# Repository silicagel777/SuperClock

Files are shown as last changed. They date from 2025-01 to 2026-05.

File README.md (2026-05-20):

# LED Matrix Super Clock

A DIY desk clock with retro-style dot matrix display

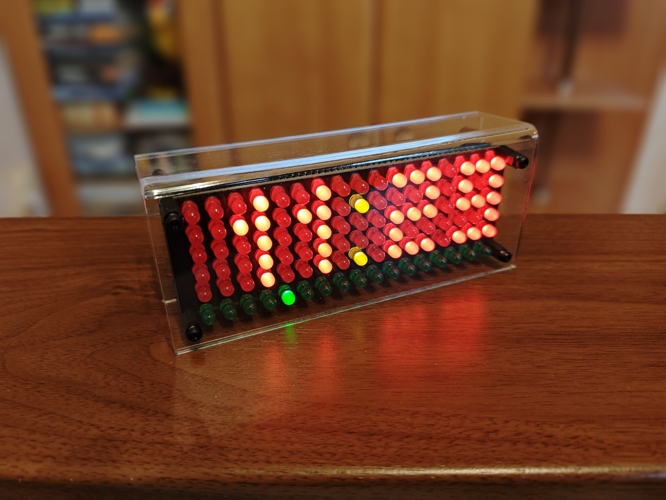
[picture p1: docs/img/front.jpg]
Front photo

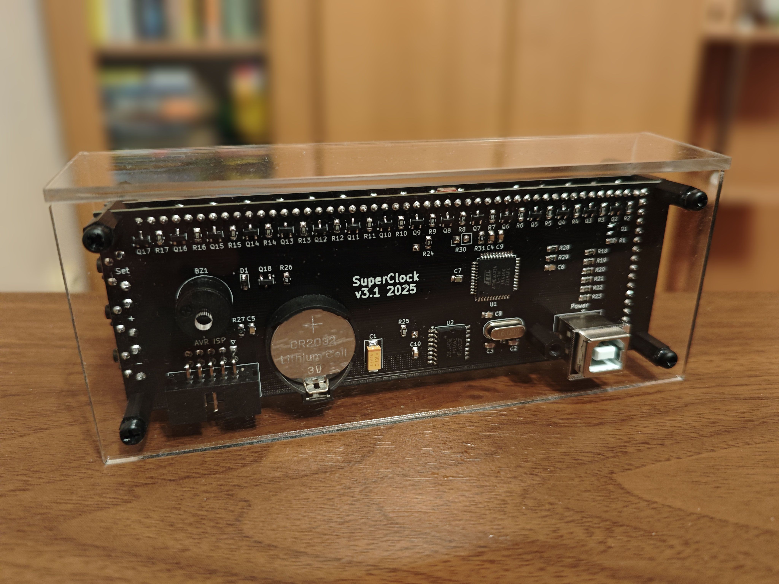
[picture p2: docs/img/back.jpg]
Back photo


## Features

- A retro-style dot matrix display:
    - 17x6 5mm LED matrix
    - Different LED colors for main area, status bar and number separator
    - No flickering, ghosting or uneven brightness
    - High refresh rate of 460Hz
    - 8-bit global brightness and 3-bit per-pixel brightness
    - Global brightness is automatically (and smoothly) adjusted by ambient conditions, just like on your phone!
- Accurate timekeeping:
    - Temperature-compensated crystal clock (DS3231SN chip)
    - Backup power to keep the clock ticking (CR2032 battery)
    - Displays minute, hour, day, weekday, month, year and even ambient temperature
    - Green status bar tracks seconds (incremented every 4s)
    - Five alarms with melody
- Intuitive (kinda) user interface with three buttons
- Cool acrylic glass frame
- Powered by any USB brick through a Type-B cable
    - Finally, a reason to pick up that old printer cable from your drawer!
- Built around ATmega32 microcontroller, with firmware written in C++
    - Uses **every** I/O pin on ATmega32, no wasted potential!
- No AI and no internet connection! (yup, that's a feature nowadays...)
- Totally open-source!

## Documentation

- [Hardware docs](docs/hardware.md)
    - Includes schematics, design files, parts list and even assembly tips
- [Frame docs](docs/frame.md)
    - Describes the acrylic glass frame
- [Software docs](docs/firmware.md)
    - How to flash firmware or set up development tools if you want to modify it
- [LED matrix notes](docs/matrix.md)
    - Notes on how the LED matrix works
- [User manual](docs/manual.md)
    - What do these buttons do?!

## TODO list

- [x] Write this readme
- [x] Make first public release
- [ ] Animated minute/hour transitions
- [ ] Reorganize font system
- [ ] More levels for highest and lowest brightness?
- [ ] Use C++ namespaces?
- [ ] Abstractions for pins and timers?
- [ ] Snake mode? :D

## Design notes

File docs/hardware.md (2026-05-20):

# Hardware notes

## PCBs

<a href="img/pcbs_outside.jpg">Photo of PCBs (outside)</a>
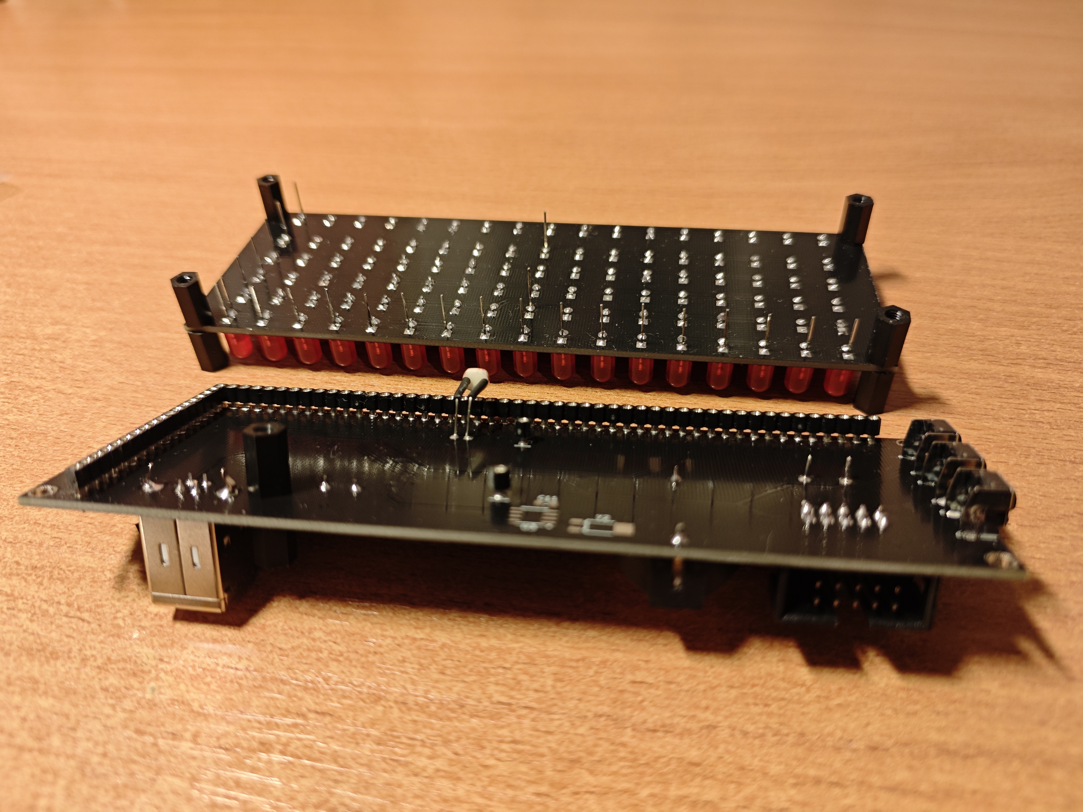
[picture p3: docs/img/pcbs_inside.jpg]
Photo of PCBs (inside)


The clock is built with two PCBs: the front one that houses LEDs (matrix) and the back one that contains everything else (controller). You can find schematic PDFs, KiCAD design files and Gerber archives here:

- [Matrix board files](../hw/matrix/)
    - [PDF schematic](../hw/matrix/SuperClockMatrix.pdf)
    - [Gerber archive](../hw/matrix/gerber/superclockmatrix.zip)
- [Controller board files](../hw/controller/)
    - [PDF schematic](../hw/controller/SuperClockController.pdf)
    - [Gerber archive](../hw/controller/gerber/superclockcontroller.zip)

The provided Gerber files can be used to order the boards from a multitude of Chinese PCB prototyping factories. I've ordered mine from [Elecrow](https://www.elecrow.com/), but you can also try [JLCPCB](https://jlcpcb.com/) or anything else. Note that these PCBs are wider than the typical 100mm limit, so you are going to pay a little bit more than usual. But it's worth it, I promise!

I recommend ordering the boards with black soldermask and no manufacturer marks (so that the factory won't write anything on the front area). Elecrow makes boards with no markings by default, while JLCPCB offers "Remove Mark" as an option.

## Parts list

### LED matrix

You are going to need a lot of LEDs, so I recommend making a bulk order instead of buying them locally one-by-one. I've bought all the LEDs in 100pcs bags from "[Chanzon Store](https://aliexpress.com/item/32283531722.html)" on AliExpress.

Reference | Quantity | Part name | Notes
--- | --- | --- | ---
\- | 83 | 5mm diffused red LED | You can pick these LEDs anywhere, although I've noticed that no-name red LEDs can be a tad dimmer than the branded ones.
\- | 17 | 5mm diffused green LED | Green LEDs exist in two variants: "green" (515-520nm) and "yellow-green" (570-575nm). You need to get the former ones, as they are **much** brighter. And, of course, if the seller doesn't describe the LED variant, you are going to receive the worst one! But don't worry if you happen to get dim LEDs, all you need is to replace a single resistor.
\- | 2 | 5mm diffused yellow LED | The only LEDs worth buying in retail, as you only need two of them! You can also try the orange ones here.

### Controller board

Reference | Quantity | Part name | Notes
--- | --- | --- | ---
BT1 | 1 | CR2032 generic holder | I don't know the correct part number for this one, but it's widely available on AliExpress, just search for "CR2032 battery holder"
BZ1 | 1 | Generic passive buzzer: 12mm x 8.5mm, 42R (5V) | I don't know the correct part number for this one either, but it's widely available on AliExpress, just search for "passive buzzer 42R"
C1 | 1 | SMD-C 100uF tantalum capacitor | I've used TAJC107K016RNJ, but this can be any matching capacitor
C2-C3 | 2 | SMD 0805 12pF ceramic capacitor | -
C4-C10 | 7 | SMD 0805 0.1uF ceramic capacitor | -
D1 | 1 | 1N5819WS | This diode is used for voltage spike protection in buzzer driving circuit
J1-J4 | 4 | Round-pin single-row machined headers | The controller board requires 1x49, 1x17, 1x1 and 1x1 round-pin machined connectors. Sadly, the first size does not exist in the wild, but you can buy a bunch of 1x40 ones and cut/combine them with ease. You can find the connectors on AliExpress, just search for "round pin female header".
J5 | 1 | USB Type-B 180-degree socket | This is the biggest USB socket, the same kind as in printers or Arduino UNO. The socket must be a vertical one, with pins on the opposite side of the socket. I don't know the correct part number for this, but you can find them on AliExpress, just search for "usb type-b socket 180"
J6 | 1 | 2x5 90-degree IDC socket | The socket for USBasp programmer, used to flash ATmega32. Part numbers vary: it can be IDC-10MR, BH-10R, DS1013-10R or something completely else. You can find them on AliExpress by searching "idc connector"
Q1-Q18 | 18 | 2N7002K | A SOT-23 N-channel MOSFET. I recommend using 2N7002K here: these come with built-in ESD protection diodes. But you can also use the more popular ones instead: 2N7002, BSS138. Just be morally prepared to replace a few busted ones, as they can be killed by ESD discharge while soldering. I don't recommend using higher-power MOSFETs like AO3400, AO3416, IRLML2502, etc, as their higher input capacitance causes slight [display ghosting](matrix.md#led-ghosting) on lowest brightness.
R18-R22, R24-R25 | 7 | SMD 0805 220R resistor | -
R23 | 1 | SMD 0805 3.3K resistor | -
R26, R31 | 2 | SMD 0805 10K resistor | -
R27-R29 | 3 | SMD 0805 4.7K resistor | -
R30 | 1 | GL5516 photo-resistor | -
SW1-SW3 | 3 | 90-degree tactile switch | I don't know the correct part number for this one, but it's widely available on AliExpress, just search for "angle tactile switch"
U1 | 1 | ATmega32A-AU | Should work with any ATmega32 in TQFP-44 package
U2 | 1 | DS3231SN | There also exists a less-accurate part called DS3231M. Both of them work, but you want to get the best one!
Y1 | 1 | HC49S 16MHz Crystal | External crystal for ATmega32
~~R1-R17~~ | ~~17~~ (do not place) | ~~SMD 0805 resistor~~ | These were used in an earlier attempt to counteract [display ghosting](matrix.md#led-ghosting), but turned out to cause more harm than good: green LEDs did not like the reverse voltage at all, and started failing in a few months! The ghosting issues were eventually resolved by other means, so don't solder these resistors at all.
~~U3~~ | ~~1~~ (do not place) | ~~DS1307ZN~~ | I've added this one just in case DS3231 chips become unavailable, but luckily that didn't happen! Don't solder DS3231 and DS1307 together, as they use the same I2C address.
~~Y2~~ | ~~1~~ (do not place) | ~~32.768kHz clock crystal~~ | External crystal for DS1307
~~C11~~ | ~~1~~ (do not place) | ~~SMD 0805 0.1uF ceramic capacitor~~ | Bypass capacitor for DS1307

### Miscellaneous

Reference | Quantity | Part name | Notes
--- | --- | --- | ---
\- | 9 | M3 10mm male-female nylon standoffs | Used to connect the boards together. You can buy a whole kit of standoffs on AliExpress: search for "m3 nylon standoff kit", they come in nice 10-cell boxes.
\- | 5 | M3 10mm female-female nylon standoffs | Used to connect the boards together.
\- | 8 | M3 nylon screws | Used to attach the acrylic frame

## Assembly notes

Assembling the boards should be fairly straightforward, but here are a few hints:

- Square pads on matrix board are LED cathodes, and round pads are LED anodes. All the LEDs are soldered in the same direction.
- LED legs from the matrix board act as connector pins for the controller board. This means that, looking at matrix board from behind, you **must not** cut the LED cathode pins on the top, LED anode pins on the right, and number separator LED anode pins at the center. Instead, carefully trim them to something around 9mm (that's for 10mm standoffs, adjust accordingly if your PCB spacers are different length).
- Mating the boards for the first time might be tricky: the round-pin machined connectors don't like misaligned stuff. To resolve this, carefully align LED legs with tweezers until they all go into the corresponding holes. Once the pins are properly aligned, further board separation/mating cycles should be much easier.
- The hole near USB socket is to provide some additional strength when the cable is inserted: you can put standoffs here to protect the controller PCB and acrylic frame from being bent too much. But don't worry if you don't have spare standoffs anymore: it seems that there is enough rigidity anyway.
- If you've never soldered SMD parts before: don't be intimidated by them! Working with SMDs is actually way easier than with through-hole ones. All the parts used here are big enough to not be annoying, and the probability of solder bridges becomes very low with a good flux. I recommend buying a hot-air soldering gun if you don't have it already, but you can assemble the controller board easily with soldering iron alone. Remember to solder the SMD parts first, then go for the through-holes.
- Be careful with DS3231SN chip: heating it too much might affect clock accuracy. I recommend soldering it with a temperature-controlled soldering iron instead of hot air gun or reflow oven.

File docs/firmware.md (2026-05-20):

# Software notes

The firmware is written in C++. It can be compiled by [avr-gcc](https://www.nongnu.org/avr-libc/user-manual/overview.html) and flashed by [avrdude](https://github.com/avrdudes/avrdude) through [USBasp](https://www.fischl.de/usbasp/). You can find the latest firmware builds in "Releases" section.

## Flashing firmware

ATmega32 doesn't come with a USB bootloader (and there are no free I/O pins for USB connection anyway), so you are going to need an external programmer tool.

There are lots of ATmega programmers around, and if you are into DIY electronics, chances are high that you already have one! I've used the [USBasp](https://www.fischl.de/usbasp/) programmer from AliExpress. If you have an Arduino board, you can try [Arduino ISP](https://docs.arduino.cc/built-in-examples/arduino-isp/ArduinoISP/) sketch
instead.

To flash firmware, do the following:

- Connect your programmer to your PC and your clock. Most USBasp clones come with a 2x5 ribbon of standard [AVR ISP pinout](https://en.m.wikipedia.org/wiki/File:Isp_headers.svg): if that's the case, just plug the cable into the IDC socket. USB power is not required, as the clock will receive power from the programmer.
- Install drivers for your programmer. For USBasp, you can consult [the official page](https://www.fischl.de/usbasp/).
- Download the programming software. My favorite is [SinaProg](https://cxem.net/software/download/SinaProg2.1.1.rar), but sadly it's very dated, and the official website is long gone. Another good (and maintained) option is [AVRDUDESS](https://github.com/ZakKemble/AVRDUDESS). Both tools are Windows-only and are GUI wrappers for the [avrdude](https://github.com/avrdudes/avrdude) tool. If you run Linux, you can use avrdude directly instead and flash firmware by running a Makefile (see below).
- A factory-fresh ATmega32 is configured to run at 1MHz. Before flashing the firmware, we need to tell it to run from the external crystal at 16MHz and configure a few other settings. This is done by setting fuse bits. You need to set **low byte** to `0xBF` and **high byte** to `0xD1`. Be careful, setting wrong fuse values can brick your chip!
    - For fuses, you need to set a low programming speed in your software, as the default 1MHz clock is not enough for ATmega32 to respond at the fastest speeds.
    - Some USBasp clones from AliExpress run a very old firmware version that doesn't allow configuring programming speed in software: they always use the fastest one instead (1.5MHz). If this happens to you, short the "JP3" jumper on the programmer, it will reduce programming speed.
    - Once the fuses are flashed, you can return to full programming speed.
    - If the chip fails to detect after fuses are flashed, carefully check the soldering around crystal: ATmega32 won't run if it can't make it oscillate.
- Download the latest `*.hex` files from the "Releases" section and load it into the programming software. Flash it, and you should see your clock come alive!

Here is a picture with AVRDUDESS buttons highlighted:

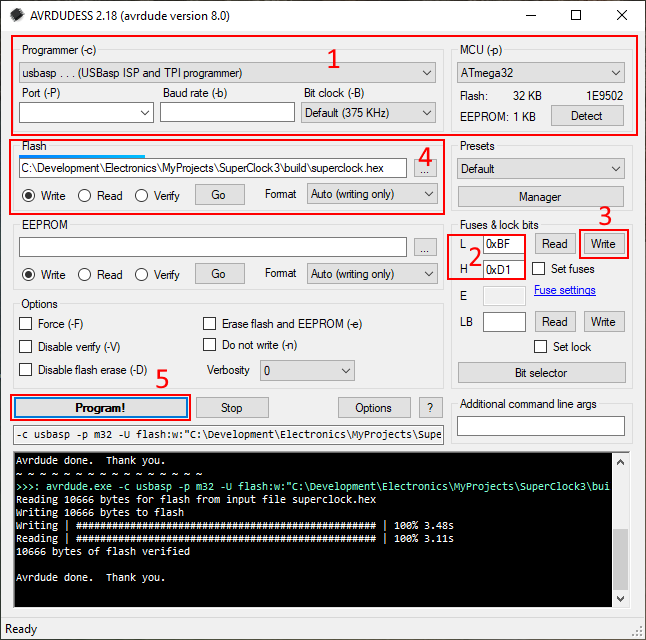
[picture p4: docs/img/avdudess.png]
AVRDUDESS UI


## Developing firmware

### Installing development tools on Windows

- Grab an `avr-gcc` build from [WinAVR](https://winavr.sourceforge.net/)
- Download `make` from [xPack](https://github.com/xpack-dev-tools/windows-build-tools-xpack)
- Download `avrdude` [binary](https://github.com/avrdudes/avrdude)
- Add all the tools to your PATH environment variable (Control Panel -> System -> Advanced System Settings -> Environment Variables). For `avr-gcc` and `make` add `bin` directories, and for `avrdude` add the directory with `avrdude.exe`.

### Installing development tools on Ubuntu or Debian

Run as root: `apt update && apt install gcc-avr binutils-avr avr-libc make avrdude`

### Using `make`

The project comes with a `Makefile` that defines a few commands. Switch to project directory and try the following:

- `make` to build a hex file (you can append `-j<NUMBER>` for parallel builds, for example `make -j16` for an 8-core 16-thread CPU)
- `make font` to update font file
- `make fuse` to write fuse bits through USBasp (do it once before flashing)
- `make flash` to flash firmware through USBasp
- `make clean` to remove build files

### Using Visual Studio Code to develop

With all the build tools in place, setting up the [code editor](https://code.visualstudio.com/) is fairly straightforward!

Firstly, install the [C/C++ plugin](https://code.visualstudio.com/docs/languages/cpp). You'll probably see an annoying pop-up once you open a `*.cpp` file, so this requirement is hard to miss anyway.

Once you are done, create `.vscode/c_cpp_properties.json` in project root to configure the C/C++ plugin. Here is mine:

```js
{
    "configurations": [
        {
            "name": "AVR",
            "includePath": [
                "${workspaceFolder}/src/"
            ],
            "windowsSdkVersion": "10.0.19041.0",
            // adjust your compiler path accordingly
            "compilerPath": "C:/MCU/gcc-avr/bin/avr-g++",
            "compilerArgs": [
                "-std=c++17",
                "-O2",
                "-DF_CPU=16000000UL",
                "-mmcu=atmega32"
            ],
            "cStandard": "c11",
            "cppStandard": "c++17",
            "intelliSenseMode": "gcc-arm"
        }
    ],
    "version": 4
}
```

Create `.vscode/tasks.json` in project root to set up build tasks. You can also install the [quick-run-panel](https://marketplace.visualstudio.com/items/?itemName=davehart.quick-run-panel) plugin to have all the build tasks in your arm's reach. This is optional, as you can just run `make` commands from your command line. Here is mine:

```js
{
    "version": "2.0.0",
    "tasks": [
        {
            "label": "build",
            "type": "shell",
            // change the following to "make -j $(getconf _NPROCESSORS_ONLN)" on Linux
            "command": "make -j $ENV:NUMBER_OF_PROCESSORS",
            "group": "build",
            "problemMatcher": [],
            "presentation": {
                "focus": true
            }
        },
        {
            "label": "run",
            "type": "shell",
            "command": "make flash",
            "problemMatcher": [],
            "group": {
                "kind": "build",
                "isDefault": true
            },
            "presentation": {
                "focus": true
            }
        },
        {
            "label": "clean",
            "type": "shell",
            "command": "make clean",
            "group": "build",
            "problemMatcher": [],
            "presentation": {
                "focus": true
            }
        },
        {
            "label": "font",
            "type": "shell",
            "command": "make font",
            "group": "build",
            "problemMatcher": [],
            "presentation": {
                "focus": true
            }
        }
    ]
}
```

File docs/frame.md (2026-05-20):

# Acrylic frame notes

<a href="img/frame.jpg">Frame photo</a>

You can further enhance the looks of your clock by laser-cutting an acrylic housing. You can find the DWG, DXF and PDF files here:

- [Acrylic frame files](../hw/frame/)

The front panel comes in two flavors: short and long. The short one only covers the front, while the long one is designed with an upper fin that can be bent to cover the top. Most shops charge a premium for acrylic bending, so I recommend ordering the usual laser cutting and then bending it yourself. Here are some tips:

- Place the acrylic on a metal surface with a 90-degree edge (some big metal box) and fix it in place with something heavy. The part you want to bend should be protruding on the side.
- Carefully heat the bend line with sweeping motions of a hot-air gun. I've set mine to 300°C
- Once the bend line softens, carefully bend the sheet

If you are ordering PCBs from [Elecrow](https://www.elecrow.com/), you can also use their acrylic cutting service and have everything in one order. I've used the 3mm transparent (000) acrylic.

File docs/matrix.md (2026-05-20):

# Notes on the LED matrix

Driving a bunch of LEDs... What could have been easier? Well, turns out the reality is hard!

## Introduction

LED matrix driving relies on a phenomenon called "[persistence of vision](https://en.wikipedia.org/wiki/Persistence_of_vision)". There is a really nice [animation](https://en.wikipedia.org/wiki/Dot_matrix#LED_matrix) on Wikipedia that I feel obliged to attach:

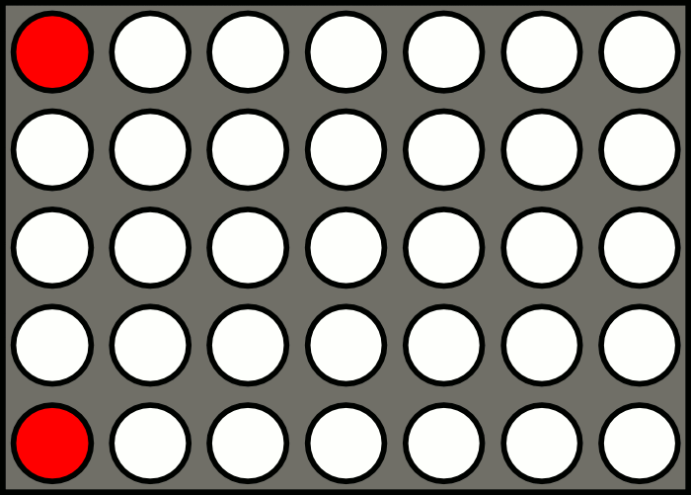
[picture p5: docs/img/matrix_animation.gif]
An animated picture of LED matrix


The LED matrix in this project is driven left to right, just like in the picture! The algorithm is simple: enable rows (LED anodes) and then enable one column (LED cathodes). Once the time comes for another column, switch the old column off, update rows and enable the new column. If you do it fast enough, you'll get an illusion of all columns working simultaneously. But the devil is, of course, in the details!

## Global brightness

Modern LEDs are bright! Good for sunny days, but not-so-good for everything else. The last thing you want is to get blinded by a clock while sneaking to your fridge at night! So, adjustable brightness is essential.

The solution sounds simple: just slap some [pulse-width modulation](https://en.wikipedia.org/wiki/Pulse-width_modulation) (PWM) on! The ATmega32 already comes with several hardware PWM channels. Unfortunately, there are caveats:

- ATmega32 has only four PWM channels, and one is already used to drive the buzzer. Not enough for every row!
- Even if there were enough channels (or we applied PWM to LED power supply), combining them with matrix-driving is tricky: the PWM and column switch frequencies might alias in a bad way, producing nasty flickering. I've learned that the hard way!

Another option is to combine matrix driving and brightness control in a single algorithm. Use one timer interrupt to enable next column, and another to shut it down. You can use the overflow interrupt for the former and compare interrupt for the latter (or vice versa, it doesn't really matter). Timer compare value can be adjusted, so we can get our adjustable brightness!

```
switch to new column here (overflow interrupt)
|
|      disable the column here (compare interrupt)
|      |
v      v
+------+--------------------------+
0      X <-- configurable        255
\_____/\__________________________/
   |                  |
 LEDs on          LEDs off
```

This idea is much better, but has a few caveats as well. Fortunately, they are manageable:

- You need to run your timer very fast to avoid flickering, and the MCU needs to have enough speed to process both interrupts. This is, essentially, PWM implemented in software. Fortunately, ATmega32 is fast enough to run an 8-bit timer at `F_CPU/8` and handle both interrupts. With `F_CPU` set to 16 MHz the speed is enough to have no perceivable flicker.
- If the timer compare value becomes too close to overflow value, interrupt calls will start overlapping, and you won't see any change in brightness. So, you lose some of the lowest and the highest brightness levels. Fortunately, there is a workaround: combine "LEDs on" and "LEDs off" phases in a single interrupt with a software delay (or without delay at all). This workaround must be enabled only when the delay value is low enough, otherwise you'll waste a lot of CPU time waiting.

## Per-pixel brightness

Per-pixel brightness is useful for smooth animation, but not as important as global brightness. I've implemented it on level above matrix driving and global brightness: 

- Each full display refresh (that's when every column gets scanned and we return to the first one) is assigned an incrementing number with an overflow value.
- If pixel brightness value is higher than this number, the pixel is lit, otherwise it's dark.
- You can only have a few brightness levels before egregious flickering becomes apparent: that's because refresh cycle frequency gets reduced for dimmed pixels. I've settled on 8 levels (3-bit): that's enough for simple effects.

## Gamma correction

If you ever tried to regulate LED brightness, you've probably seen this phenomenon: for the first few levels brightness change is very fast, but for the last few levels, brightness change is very slow and barely noticeable.

This happens because our eyes do not perceive brightness linearly, but rather do it logarithmically. So, to provide evenly spaced brightness levels, you need to apply the procedure of [gamma correction](https://en.wikipedia.org/wiki/Gamma_correction). For LEDs this usually involves something like fitting your original brightness to `[0.0, 1.0]` range, raising it to a power of three (`gamma=3.0`), and then resizing it back to match your PWM peripheral scale.

The biggest annoyance here is that a lot of PWM levels are going to be unused, so with 8-bit PWM you'll have way less than 255 distinguishable brightness levels. And for 3-bit PWM there is simply not enough resolution for any meaningful gamma correction.

Fortunately, this LED display adjusts global brightness from ambient conditions! Gamma-correction is not needed here, as we aren't accepting user input: we simply match an existing real-world brightness reading that came from a photo-resistor.

As for the per-pixel brightness: it's not very important, and animation frames can be adjusted to account for uneven brightness levels.

## Automatic brightness flicker

Automatic brightness can be very janky. You've probably seen this on older smartphones: for some ambient brightness conditions, display brightness will annoyingly toggle back and forth between two levels.

There are a few solutions to this:

- Implement something close to a [Schmitt trigger](https://en.wikipedia.org/wiki/Schmitt_trigger) in software. This is especially useful when there are few brightness levels that are spaced far apart.
- Apply some filtering to your sensor data to avoid janky readings.

This LED matrix currently employs the second trick: all photo-resistor readings are passed through a first-order IIR filter. This is the digital equivalent of an [RC circuit](https://en.wikipedia.org/wiki/RC_circuit), and is also known as [exponential smoothing](https://en.wikipedia.org/wiki/Exponential_smoothing). Seems good enough!

## Uneven column brightness

If column brightness depends on the amount of lit pixels in it, then your column drivers are not powerful enough. This is very common for displays that use MCU or 74HC595 pins to drive LEDs. The ATmega32 I/Os are only rated up to 40mA, and 74HC595 outputs are only rated up to 35mA. But a single 5mm LED can be safely driven up to 20mA (or more in short bursts): there is just not enough power to drive a bunch of them!

The solution is to use high-current driver ICs, or add transistor switches. This display uses the latter: all the columns are driven through MOSFETs, so column brightness is always consistent.

## LED ghosting

A very common issue for DIY LED matrix displays is ghosting. The most common cause is software defects: it can happen when LED rows are reconfigured without disabling the column first. If the display is scanned left-to-right, you'll see ghosts to the **left side** of lit pixels.

But there can also be another cause for ghosting: **parasitic capacitance**. Turns out, that LEDs are also capacitors and can store a tiny charge. On fast refresh speeds and small brightness levels this can result in ghosting as well! If display is scanned left-to-right, you'll see a ghosting trail to the **right side** of lit pixels.

The second issue is way nastier, since it can't be fully defeated in software. It can be somewhat reduced by several workarounds, though:

- If no rows in current column are lit, do not enable this column at all!
- If some rows in current column are lit, keep them enabled even when the column is already disabled. Reconfigure them only right before you are ready to enable the next column.

The definitive fix is, however, the hardware one:

- Use a push-pull driver for LED anodes (or add some pull-down resistors), this will help discharge the capacitance in LEDs.
- Use MOSFETs with low parasitic capacitance for LED cathodes (or use BJTs instead), so you won't have extra capacitance on the low side.
    - You might also be tempted to use push-pull drivers (or pull-up resistors) for cathodes as well, but I don't recommend this: some LED types don't like the reverse voltage at all! My green LEDs began failing in a few months after trying that: they slowly started conducting in reverse, and the whole display went wrong.

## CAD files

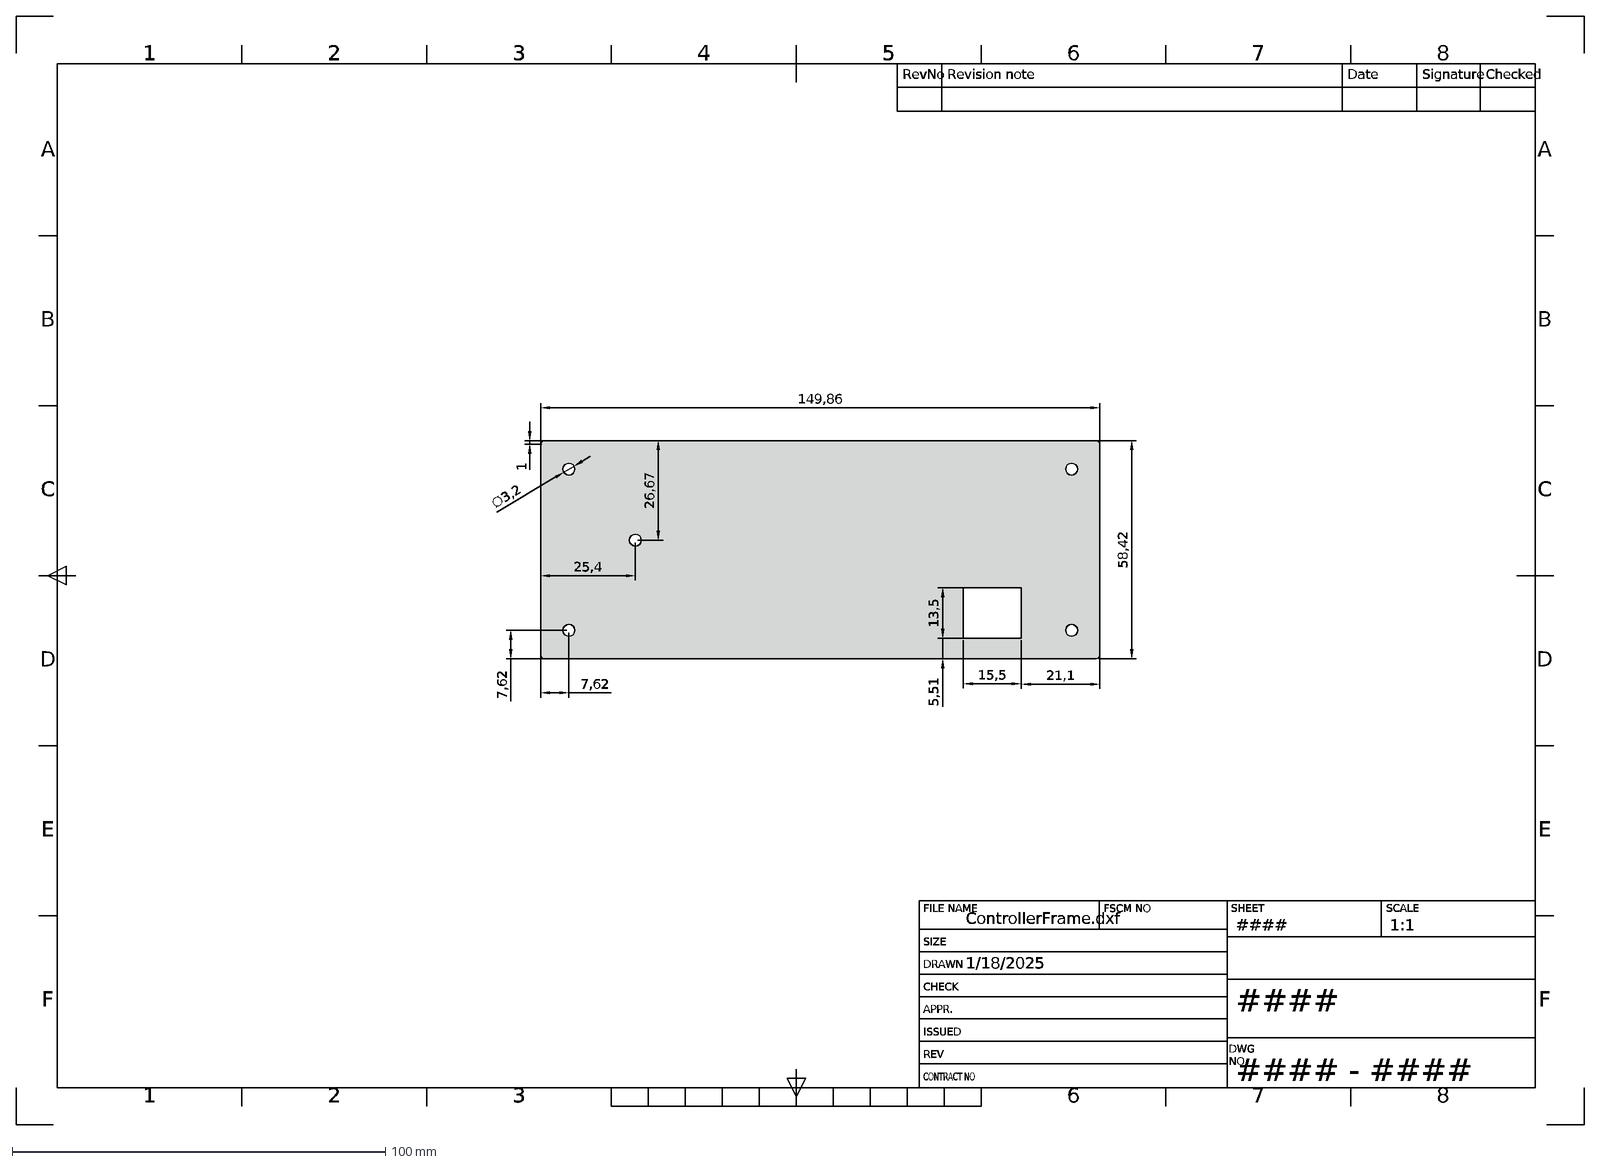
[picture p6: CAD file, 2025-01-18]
hw/frame/ControllerFrame.dxf
####
#### - ####
1:1
ControllerFrame.dxf
1/18/2025
F
1
E
D
3
2
C
B
A
4
7
6
8
5
RevNo
Revision note
Date
Signature
Checked
FSCM NO
SIZE
REV
CONTRACT NO
APPR.
ISSUED
CHECK
DRAWN
FILE NAME
SCALE
SHEET
DWG NO
7,62
149,86
58,42
∅3,2
15,5
13,5
21,1
5,51
25,4
26,67

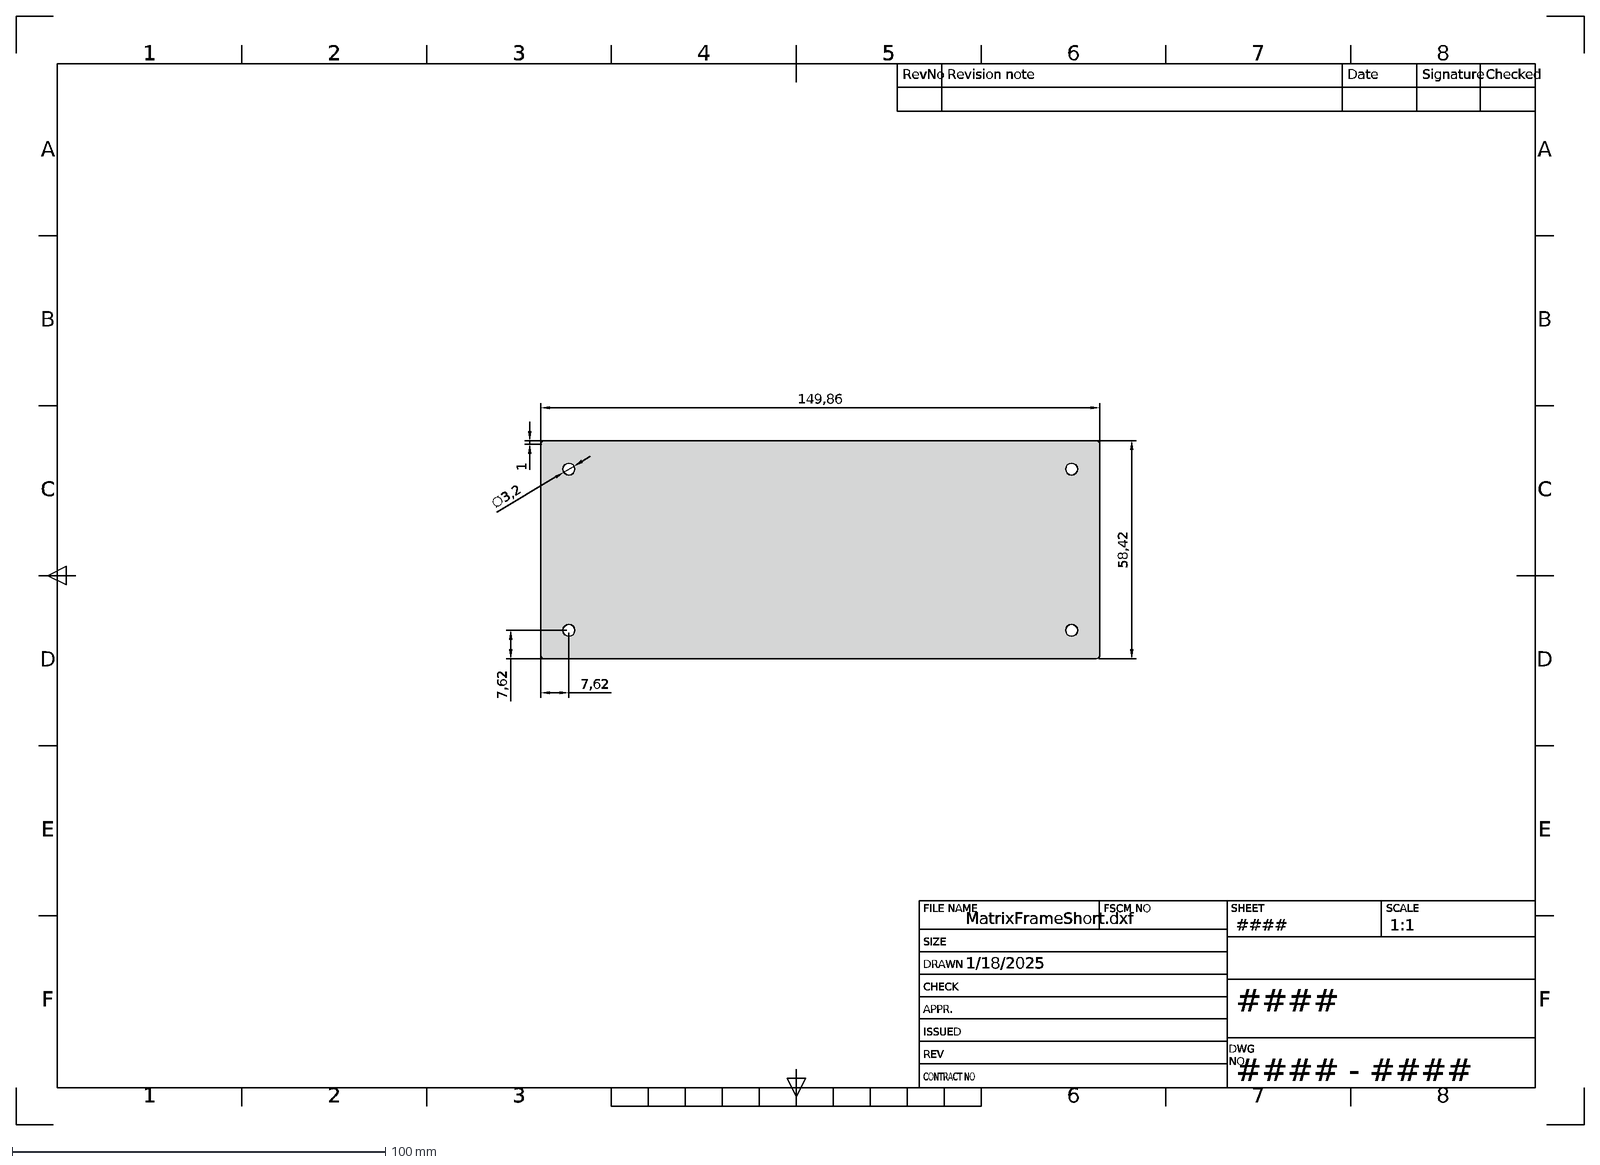
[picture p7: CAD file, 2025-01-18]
hw/frame/MatrixFrameShort.dxf
####
#### - ####
1:1
MatrixFrameShort.dxf
1/18/2025
F
1
E
D
3
2
C
B
A
4
7
6
8
5
RevNo
Revision note
Date
Signature
Checked
FSCM NO
SIZE
REV
CONTRACT NO
APPR.
ISSUED
CHECK
DRAWN
FILE NAME
SCALE
SHEET
DWG NO
7,62
149,86
58,42
∅3,2

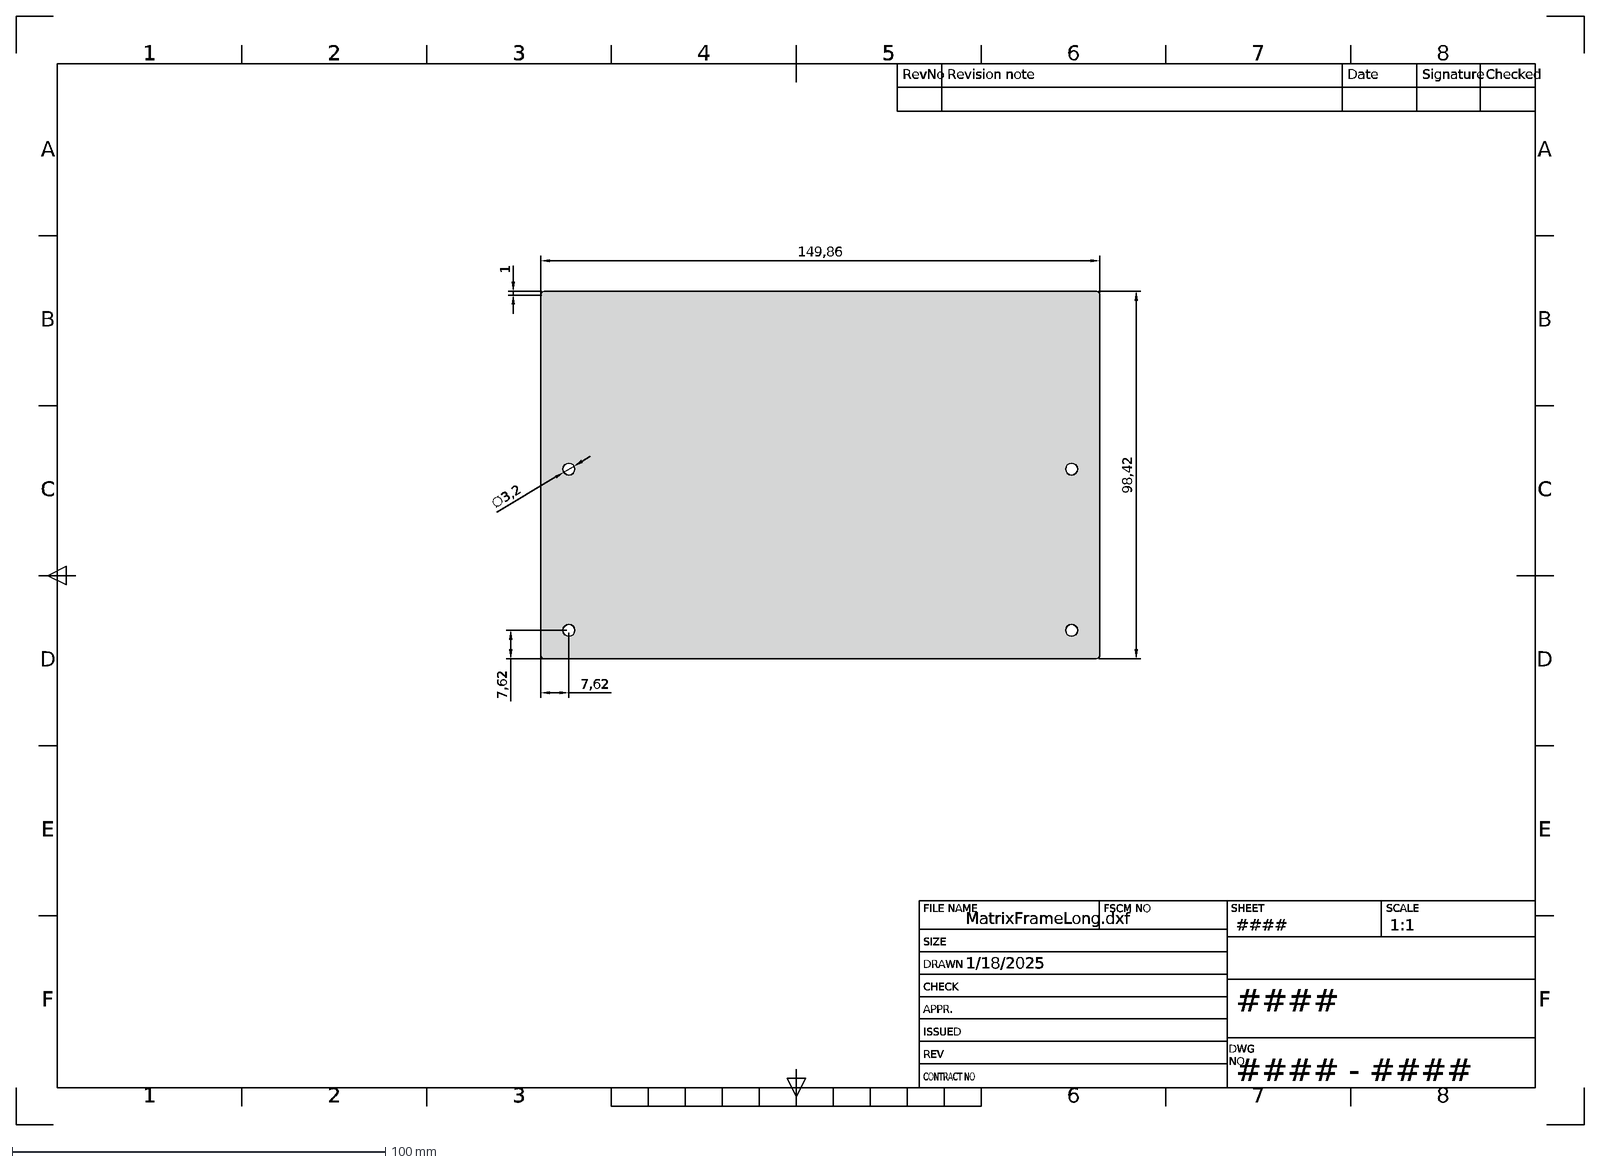
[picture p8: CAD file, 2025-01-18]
hw/frame/MatrixFrameLong.dxf
####
#### - ####
1:1
MatrixFrameLong.dxf
1/18/2025
F
1
E
D
3
2
C
B
A
4
7
6
8
5
RevNo
Revision note
Date
Signature
Checked
FSCM NO
SIZE
REV
CONTRACT NO
APPR.
ISSUED
CHECK
DRAWN
FILE NAME
SCALE
SHEET
DWG NO
7,62
∅3,2
149,86
98,42

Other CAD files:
hw/frame/ControllerFrame.dwg
hw/frame/MatrixFrameLong.dwg
hw/frame/MatrixFrameShort.dwg

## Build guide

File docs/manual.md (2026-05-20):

# User manual

## User interface

The clock comes with three buttons: `MODE`, `PLUS` and `MINUS`. Press `MODE` button to toggle between main modes. Hold `MODE` button to enter setup modes. `PLUS` and `MINUS` actions are relative to current mode.

Here is a mode list with corresponding button actions:

- Main modes:
    - "Clock mode":
        - `MODE` (press): go to "alarm mode"
        - `MODE` (hold): go to "clock setup mode"
        - `PLUS` (press): show date for a few seconds
        - `PLUS` (hold): show year for a few seconds
        - `MINUS` (press): show weekday for a few seconds
        - `MINUS` (hold): show ambient temperature for a few seconds
    - "Alarm view mode"
        - `MODE` (press): go to "stopwatch mode"
        - `MODE` (hold): go to "alarm setup mode"
        - `PLUS` (press): show next alarm
        - `PLUS` (hold): enable/disable current alarm
        - `MINUS` (press): show previous alarm
        - `MINUS` (hold): enable/disable current alarm
    - "Stopwatch mode"
        - `MODE` (press): go to "display test mode"
        - `MODE` (hold): reset stopwatch
        - `PLUS` (press): run or pause stopwatch
        - `MINUS` (press): run or pause stopwatch
    - "Display test mode"
        - `MODE` (press): go to "clock mode"
- Auxiliary modes:
    - "Clock setup mode" and "Alarm setup mode"
        - `MODE` (press): advance through numbers (or finish setup if it's the last number)
        - `MODE` (hold): finish setup early
        - `PLUS` (press): increase number by one
        - `PLUS` (hold): increase number by many
        - `MINUS` (press): decrease number by one
        - `MINUS` (hold): decrease number by many
    - "Alarm alert mode"
        - This one appears when an alarm fires up, press any button to stop and go to "clock mode"

## Clock calibration

DS3231 supports oscillator calibration through the "aging" register. The last screen of "Clock setup mode" sets the register value:

- The initial value is 0 (displayed as `C+00`), maximum is +127, minimum is -128.
- Positive values slow down the clock (seconds become longer)
- Negative values speed up the clock (seconds become shorter)
- Adjustment step is approximately 0.1ppm for DS3231SN or 0.12ppm for DS3231M.
- The value is retained even if the battery is taken out (there is a backup in EEPROM)

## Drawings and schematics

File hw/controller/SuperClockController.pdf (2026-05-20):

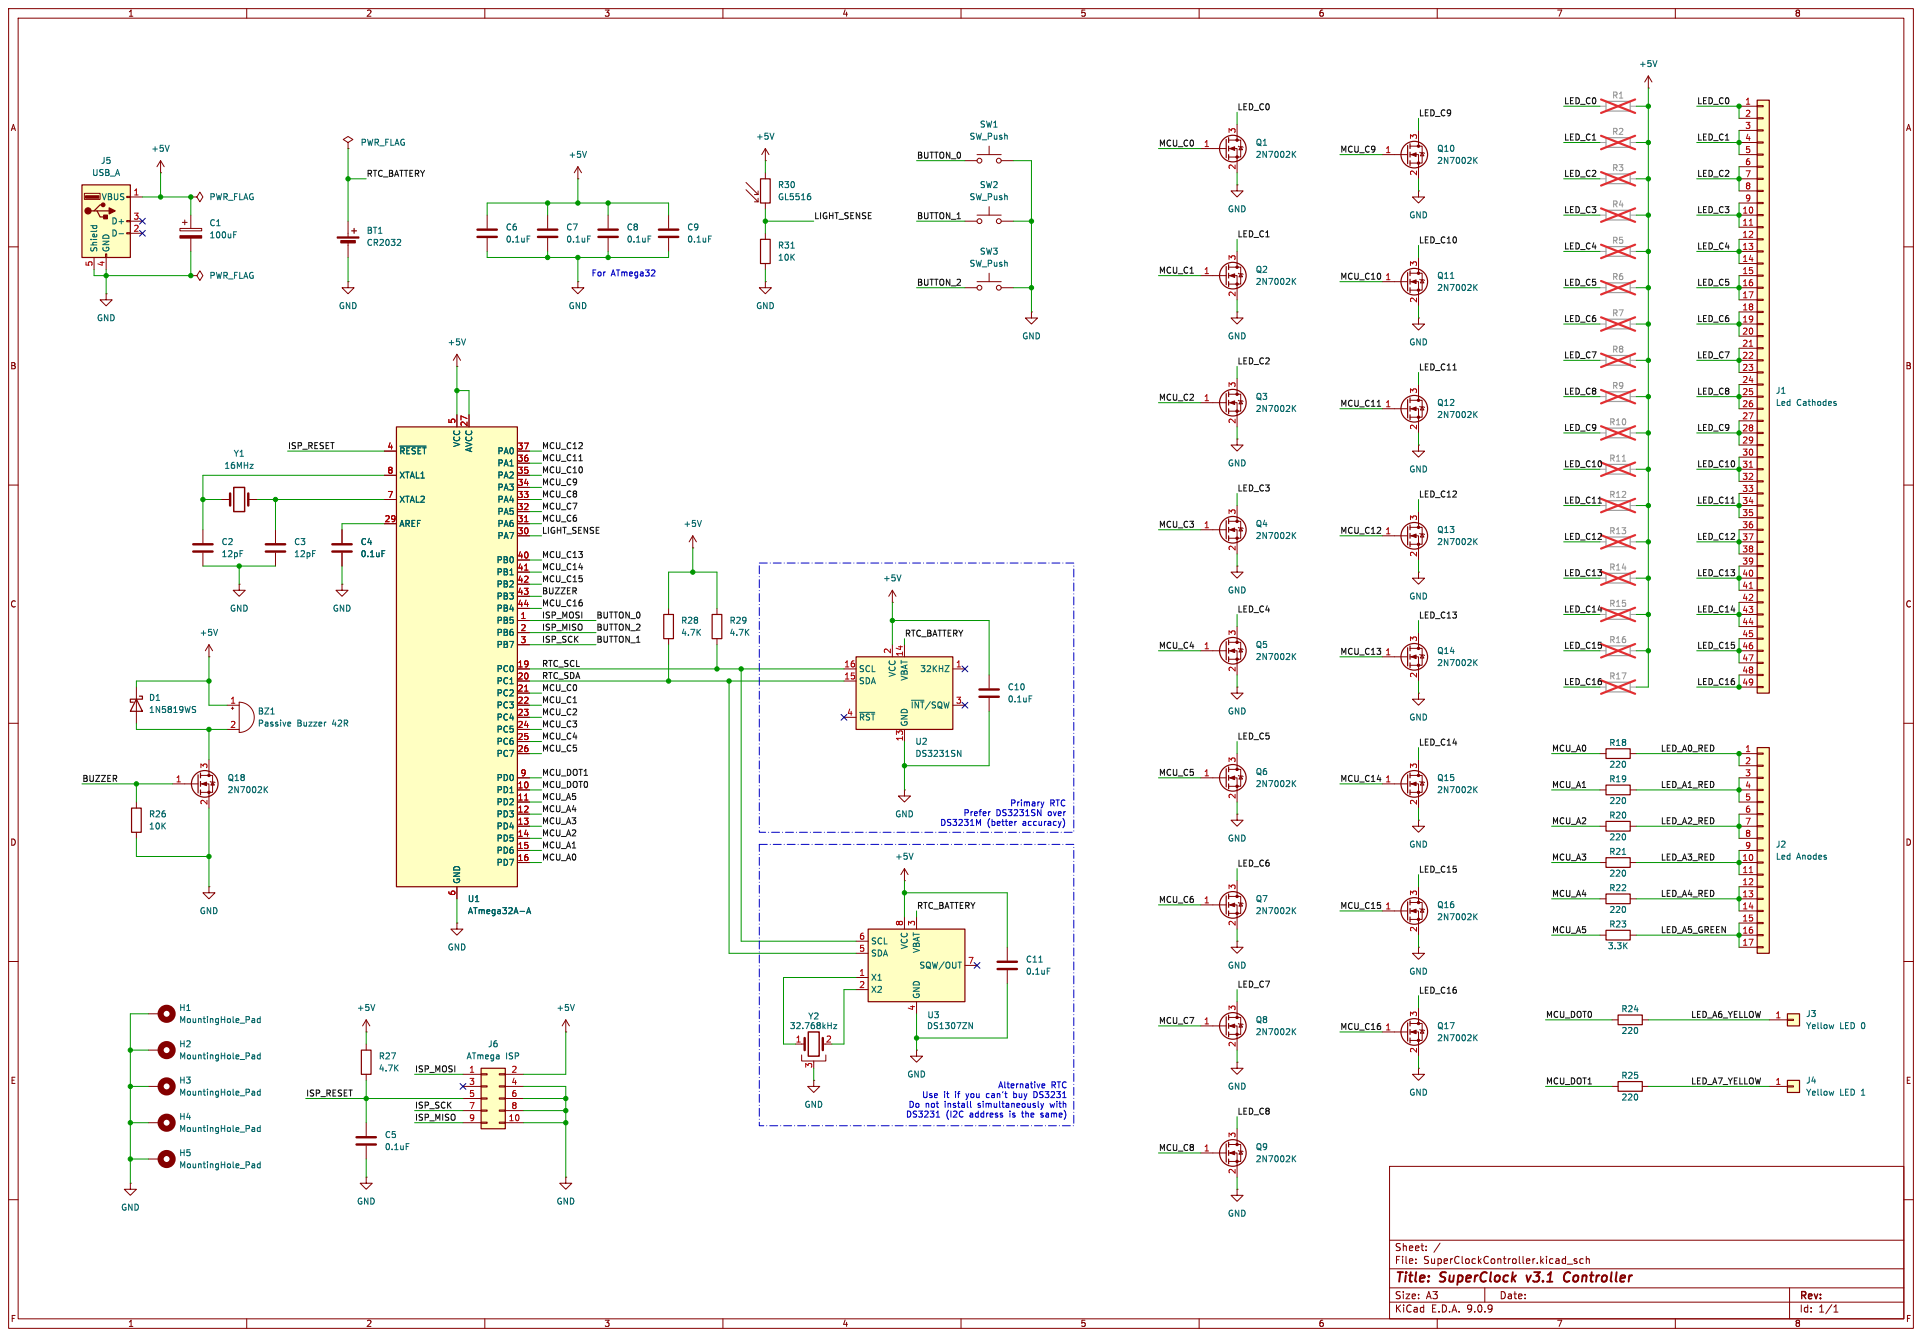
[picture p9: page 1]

Prefer DS3231SN over DS3231M (better accuracy)

Id: 1/1 Title: SuperClock v3.1 Controller File: SuperClockController.kicad_sch Sheet: /

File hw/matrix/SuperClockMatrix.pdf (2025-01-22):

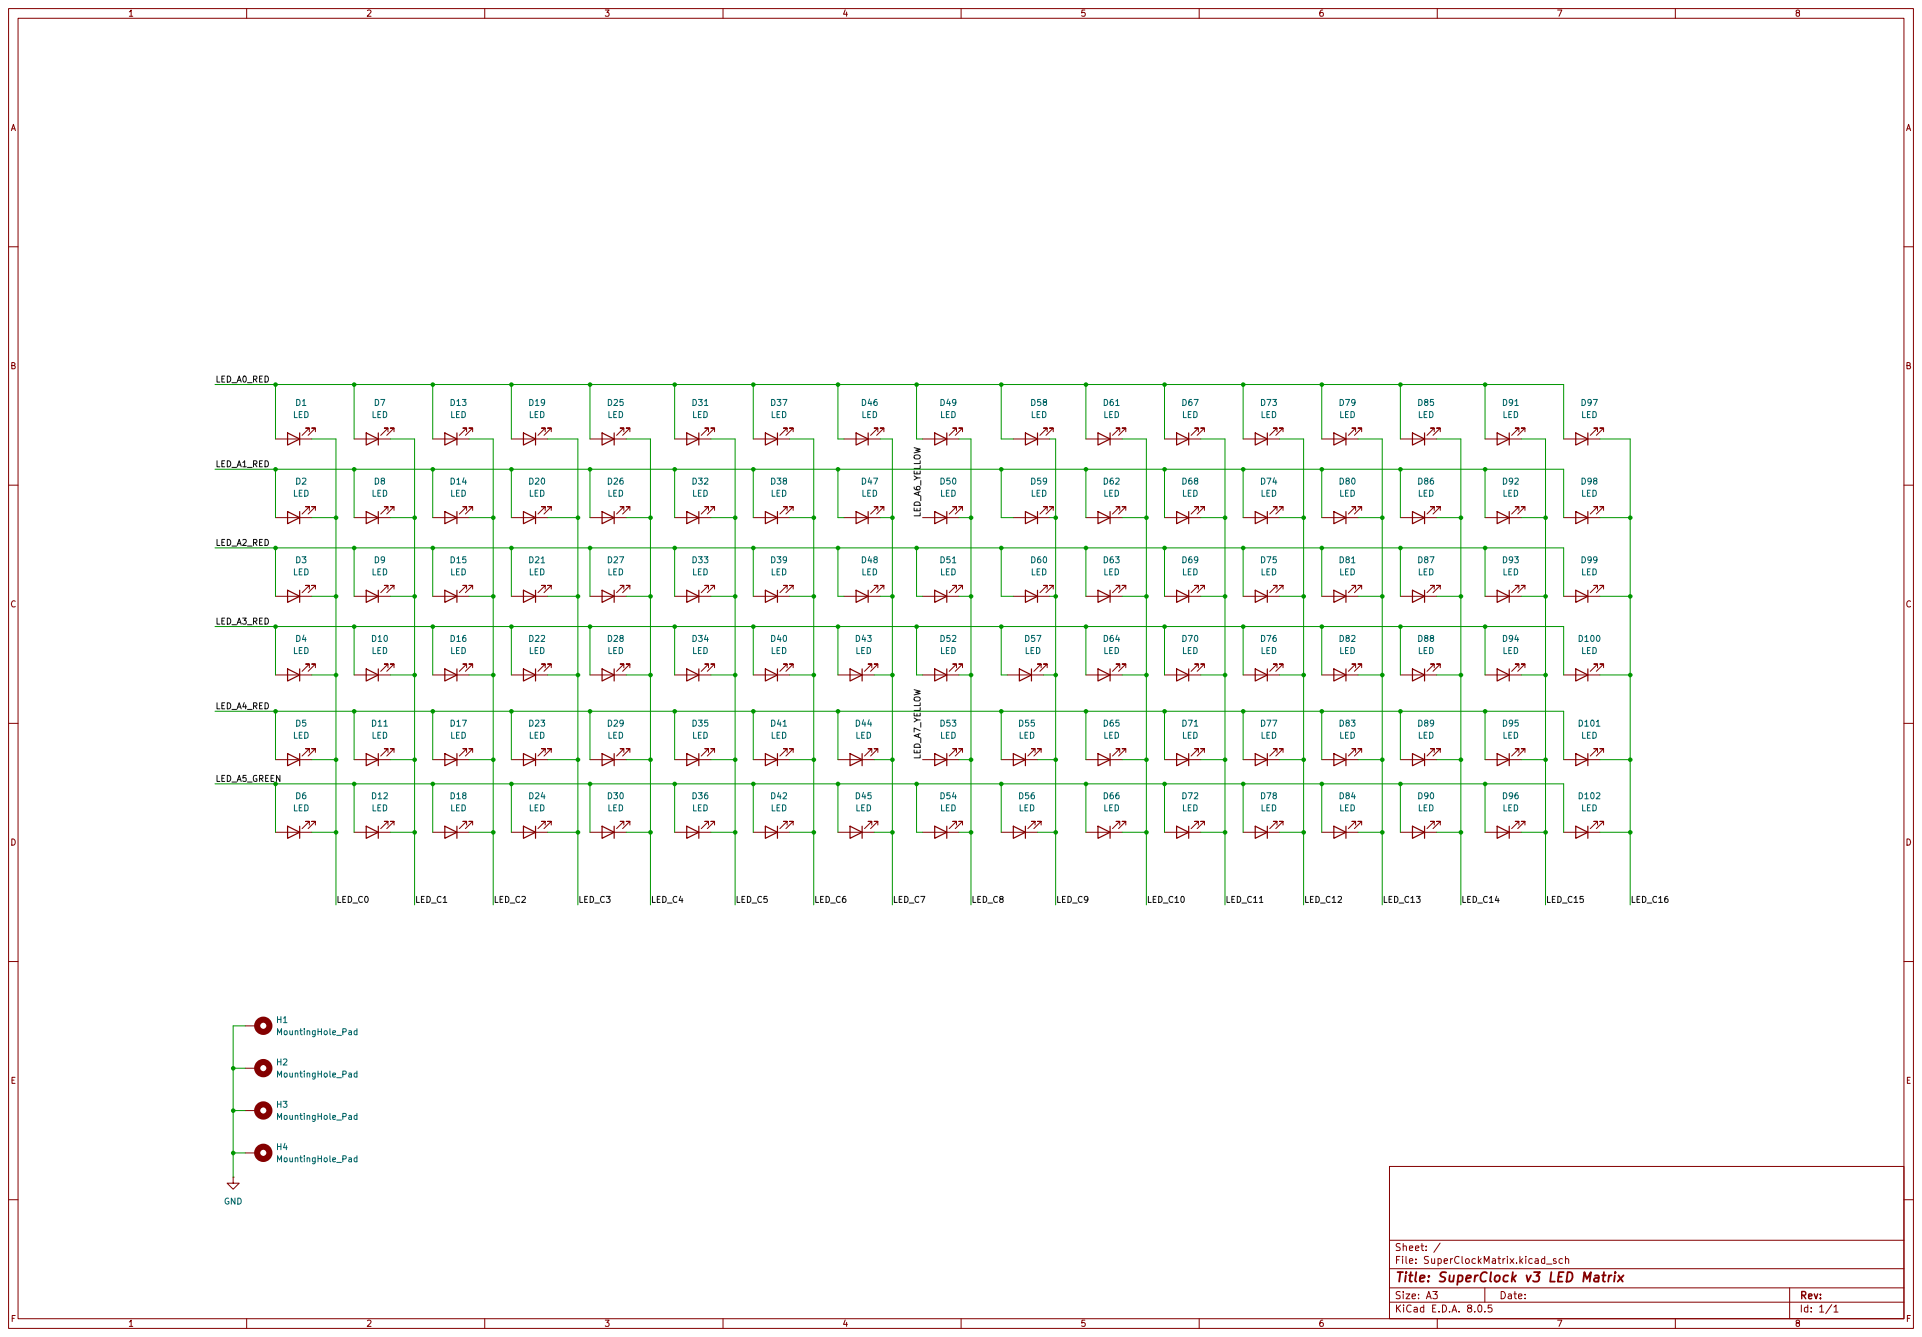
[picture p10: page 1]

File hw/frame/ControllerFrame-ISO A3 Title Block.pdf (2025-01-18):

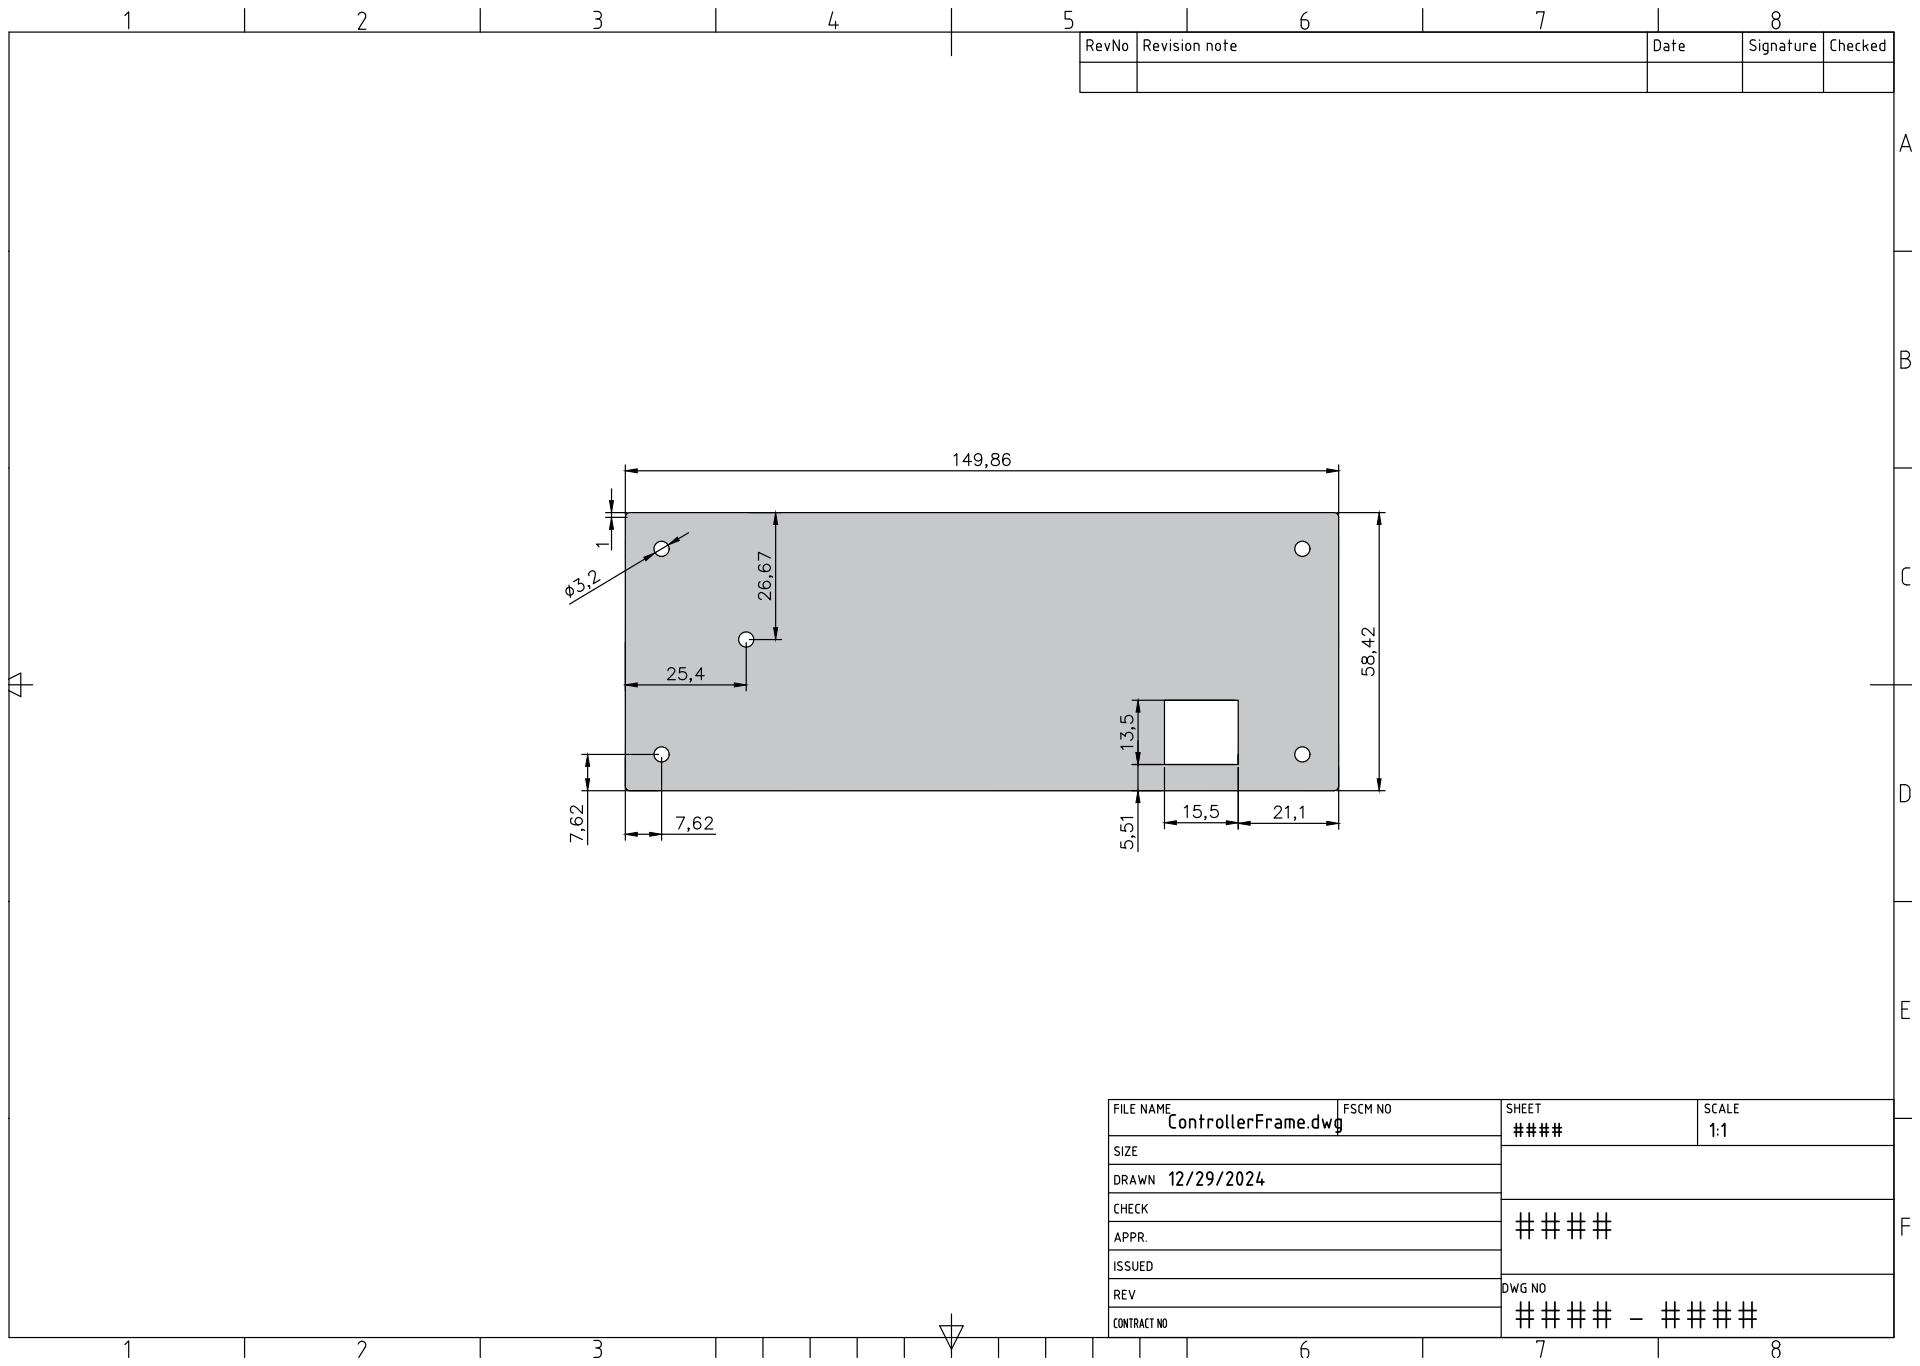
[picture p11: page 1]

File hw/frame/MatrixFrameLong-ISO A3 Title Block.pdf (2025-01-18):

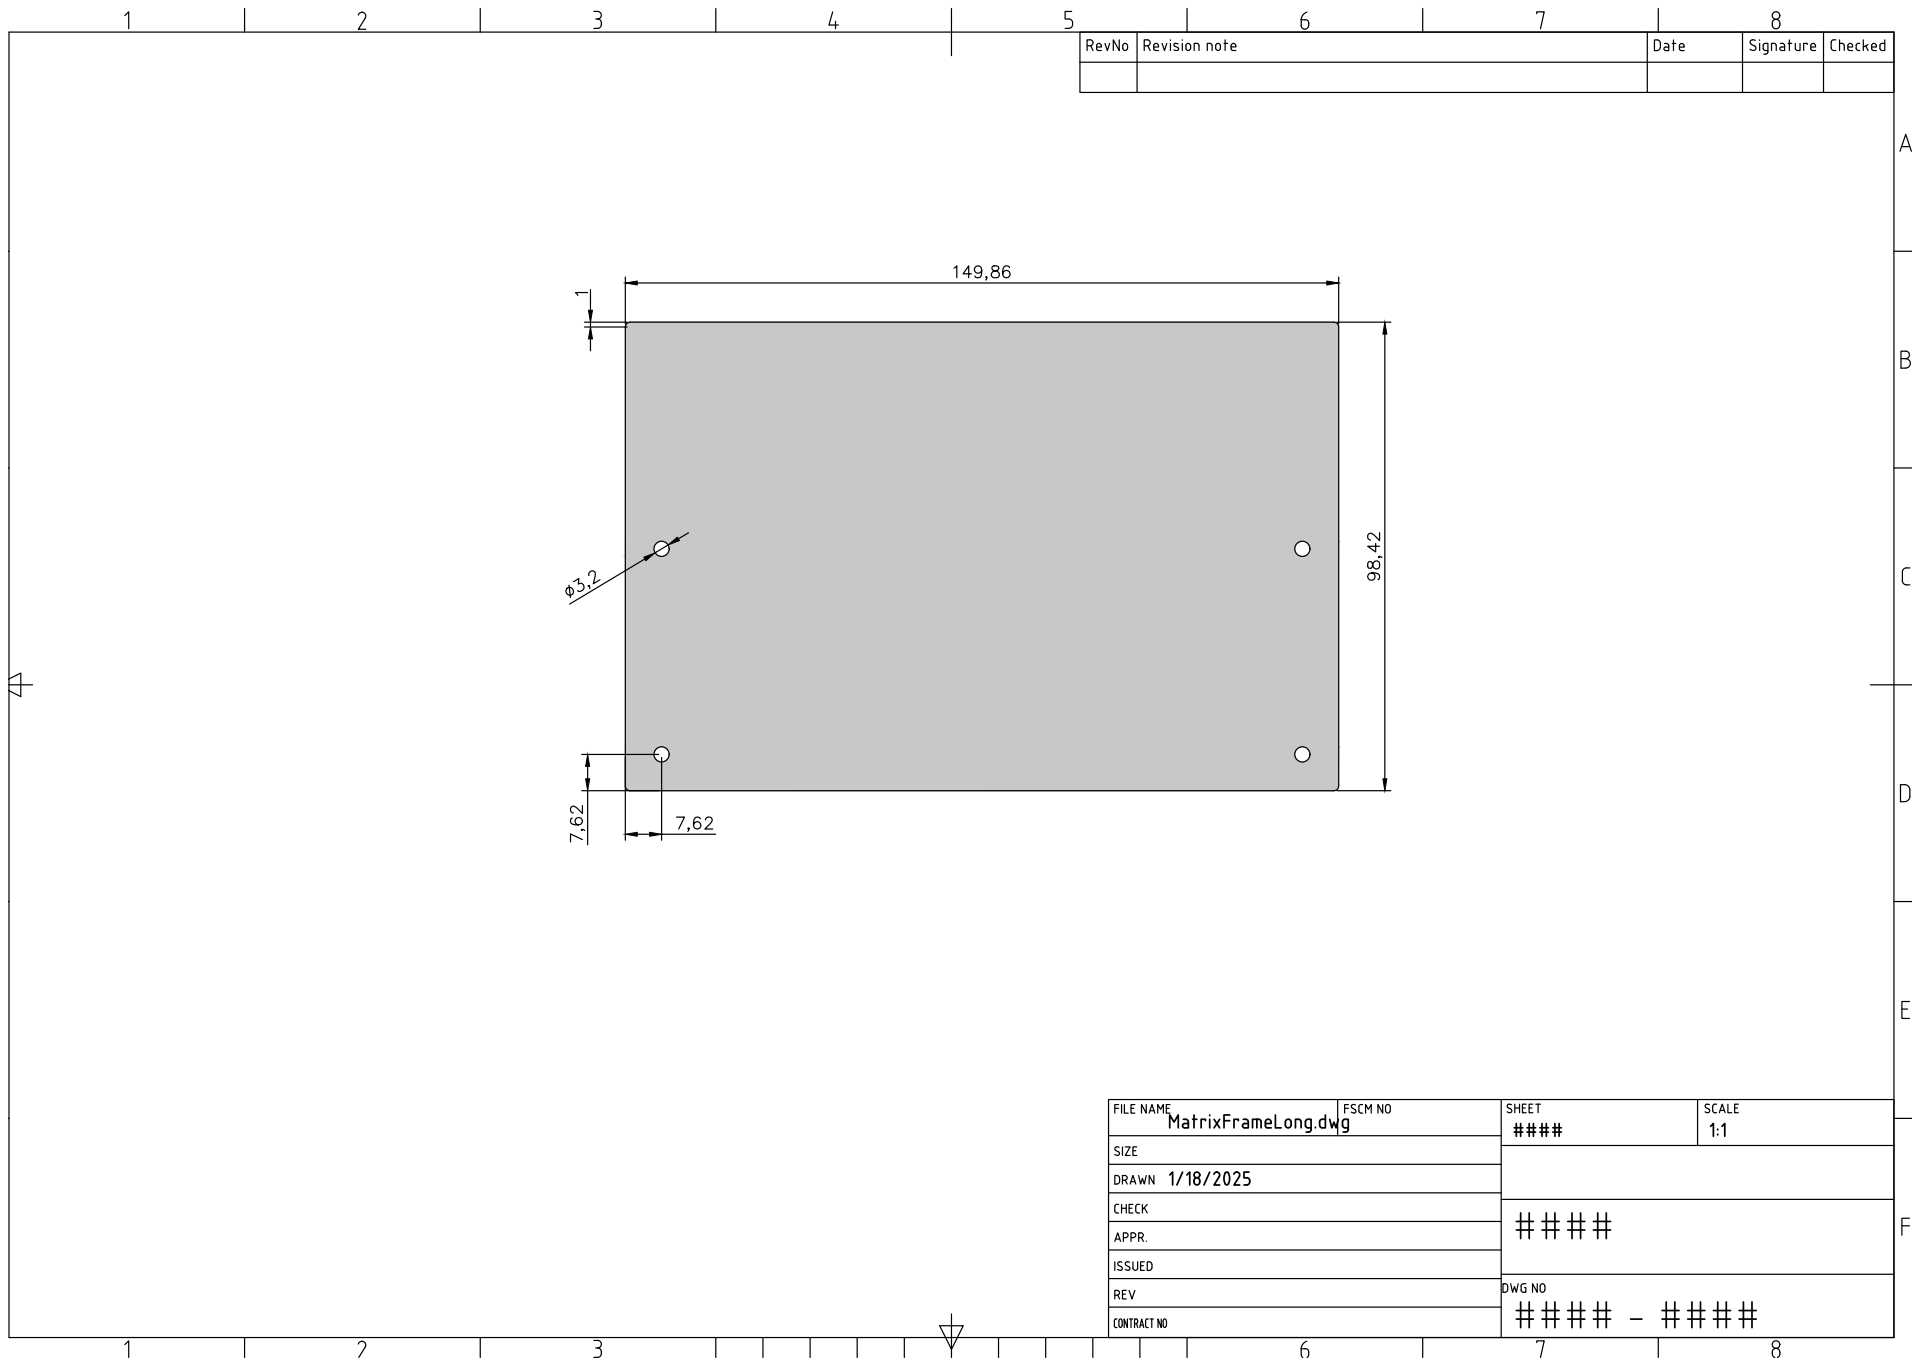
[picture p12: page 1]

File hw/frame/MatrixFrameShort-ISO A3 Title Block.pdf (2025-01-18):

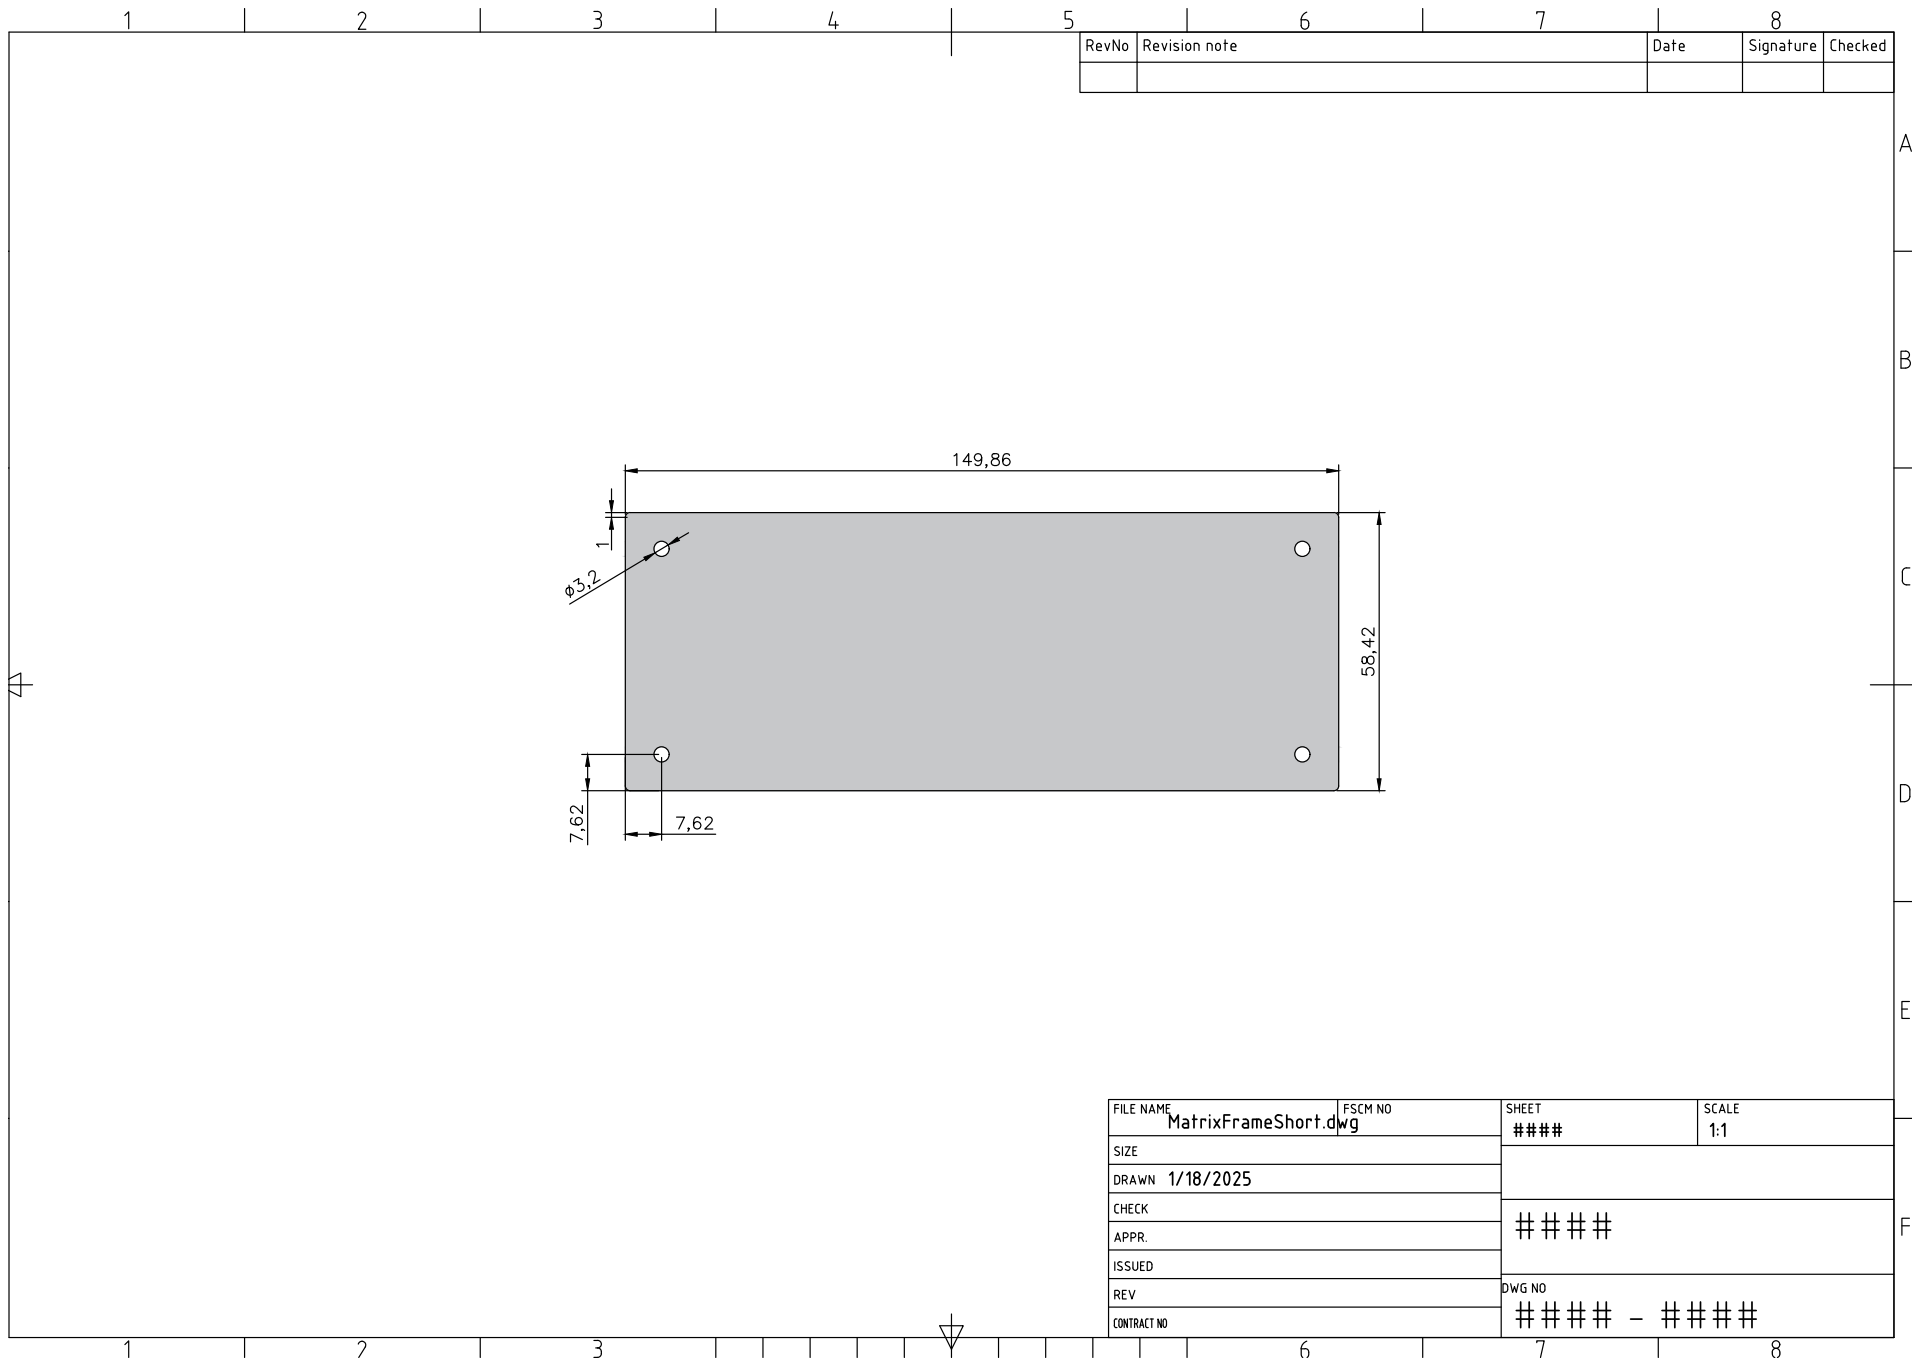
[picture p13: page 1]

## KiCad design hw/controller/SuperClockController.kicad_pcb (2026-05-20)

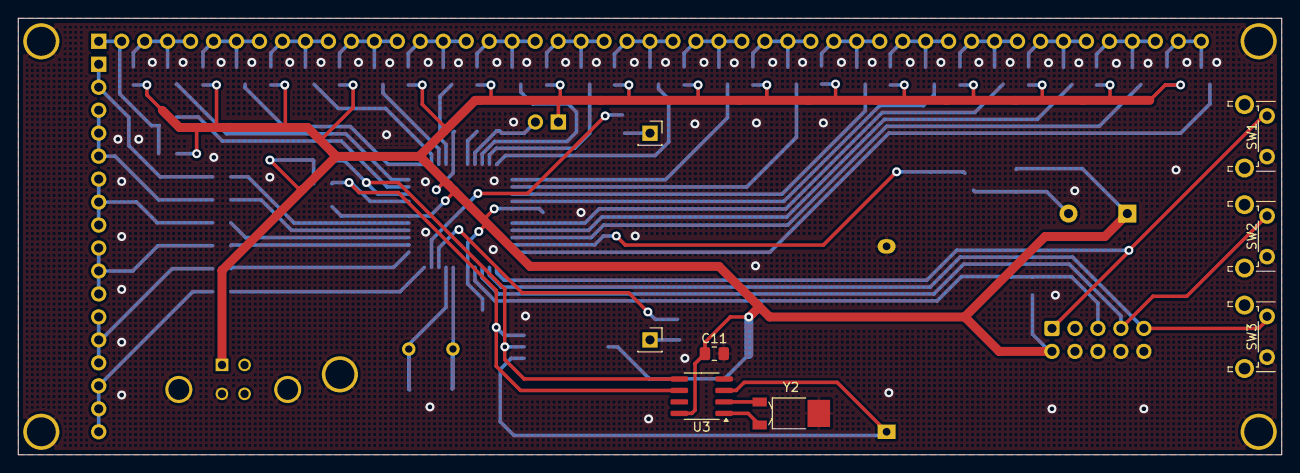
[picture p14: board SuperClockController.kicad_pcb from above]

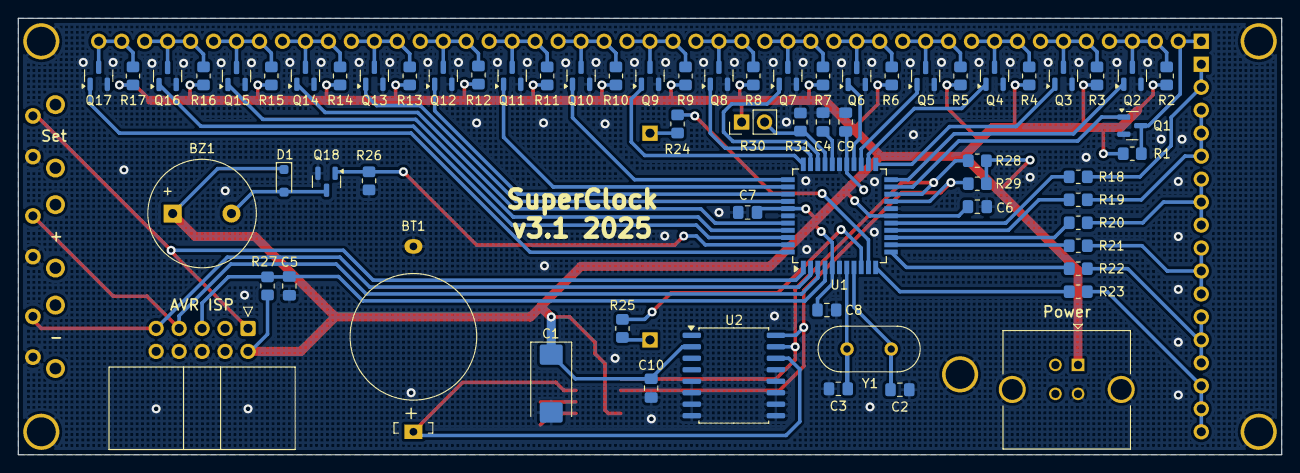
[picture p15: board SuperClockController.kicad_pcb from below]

Board: 2 copper layers, 139.7 x 48.3 mm, 82 parts (67 on the bottom side), 67 nets.

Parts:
BT1: CR2032; Battery_CR2032
BZ1: Passive Buzzer 42R; Buzzer_12x8.5
C1: 100uF; CP_EIA-7343-31_Kemet-D_Pad2.25x2.55mm_HandSolder
C2, C3: 12pF; C_0805_2012Metric_Pad1.18x1.45mm_HandSolder
C4, C5, C6, C7, C8, C9, C10, C11: 0.1uF; C_0805_2012Metric_Pad1.18x1.45mm_HandSolder
D1: 1N5819WS; D_SOD-323_HandSoldering
H1, H2, H3, H4, H5: MountingHole_Pad; MountingHole_3.2mm_M3_SmallPad
J1: Led Cathodes; PinSocket_1x49_P2.54mm_Vertical
J2: Led Anodes; PinSocket_1x17_P2.54mm_Vertical
J3: Yellow LED 0; PinSocket_1x01_P2.54mm_Vertical
J4: Yellow LED 1; PinSocket_1x01_P2.54mm_Vertical
J5: USB_A; USB_B_TE_5787834_Vertical
J6: ATmega ISP; IDC-Header_2x05_P2.54mm_Horizontal
Q1, Q2, Q3, Q4, Q5, Q6, Q7, Q8, Q9, Q10, Q11, Q12, Q13, Q14, Q15, Q16, Q17, Q18: 2N7002K; SOT-23
R1, R2, R3, R4, R5, R6, R7, R8, R9, R10, R11, R12, R13, R14, R15, R16, R17: R_0805_2012Metric_Pad1.20x1.40mm_HandSolder
R18, R19, R20, R21, R22, R24, R25: 220; R_0805_2012Metric_Pad1.20x1.40mm_HandSolder
R23: 3.3K; R_0805_2012Metric_Pad1.20x1.40mm_HandSolder
R26, R31: 10K; R_0805_2012Metric_Pad1.20x1.40mm_HandSolder
R27, R28, R29: 4.7K; R_0805_2012Metric_Pad1.20x1.40mm_HandSolder
R30: GL5516; PinHeader_1x02_P2.54mm_Vertical
SW1, SW2, SW3: SW_Push; SW_Tactile_SPST_Angled_PTS645Vx39-2LFS
U1: ATmega32A-A; TQFP-44_10x10mm_P0.8mm
U2: DS3231SN; SOIC-16W_7.5x10.3mm_P1.27mm
U3: DS1307ZN; SOIC-8_3.9x4.9mm_P1.27mm
Y1: 16MHz; Crystal_HC49-U_Vertical
Y2: 32.768kHz; Crystal_SMD_MicroCrystal_MS1V-T1K

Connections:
+5V: BZ1.1 (+), C1.1, C6.1, C7.1, C8.1, C9.1, C10.1, C11.1, D1.1 (K), J5.1 (VBUS), J6.2, R1.2, R2.2, R3.2, R4.2, R5.2, R6.2, R7.2, R8.2, R9.2, R10.2, R11.2, R12.2, R13.2, R14.2, R15.2, R16.2, R17.2, R27.1, R28.1, R29.1, R30.1, U1.5 (VCC), U1.17 (VCC), U1.27 (AVCC), U1.38 (VCC), U2.2 (VCC), U3.8 (VCC)
/BUTTON_0: J6.1, SW1.1, U1.1 (PB5)
/BUTTON_1: J6.7, SW2.1, U1.3 (PB7)
/BUTTON_2: J6.9, SW3.1, U1.2 (PB6)
/BUZZER: Q18.1 (G), R26.1, U1.43 (PB3)
/ISP_RESET: C5.1, J6.5, R27.2, U1.4 (~RESET)
/LED_A0_RED: J2.1, J2.2, R18.2
/LED_A1_RED: J2.3, J2.4, J2.5, R19.2
/LED_A2_RED: J2.6, J2.7, J2.8, R20.2
/LED_A3_RED: J2.9, J2.10, J2.11, R21.2
/LED_A4_RED: J2.12, J2.13, J2.14, R22.2
/LED_A5_GREEN: J2.15, J2.16, J2.17, R23.2
/LED_A6_YELLOW: J3.1, R24.2
/LED_A7_YELLOW: J4.1, R25.2
/LED_C0: J1.1, J1.2, Q1.3 (D), R1.1
/LED_C1: J1.3, J1.4, J1.5, Q2.3 (D), R2.1
/LED_C2: J1.6, J1.7, J1.8, Q3.3 (D), R3.1
/LED_C3: J1.9, J1.10, J1.11, Q4.3 (D), R4.1
/LED_C4: J1.12, J1.13, J1.14, Q5.3 (D), R5.1
/LED_C5: J1.15, J1.16, J1.17, Q6.3 (D), R6.1
/LED_C6: J1.18, J1.19, J1.20, Q7.3 (D), R7.1
/LED_C7: J1.21, J1.22, J1.23, Q8.3 (D), R8.1
/LED_C8: J1.24, J1.25, J1.26, Q9.3 (D), R9.1
/LED_C9: J1.27, J1.28, J1.29, Q10.3 (D), R10.1
/LED_C10: J1.30, J1.31, J1.32, Q11.3 (D), R11.1
/LED_C11: J1.33, J1.34, J1.35, Q12.3 (D), R12.1
/LED_C12: J1.36, J1.37, J1.38, Q13.3 (D), R13.1
/LED_C13: J1.39, J1.40, J1.41, Q14.3 (D), R14.1
/LED_C14: J1.42, J1.43, J1.44, Q15.3 (D), R15.1
/LED_C15: J1.45, J1.46, J1.47, Q16.3 (D), R16.1
/LED_C16: J1.48, J1.49, Q17.3 (D), R17.1
/LIGHT_SENSE: R30.2, R31.1, U1.30 (PA7)
/MCU_A0: R18.1, U1.16 (PD7)
/MCU_A1: R19.1, U1.15 (PD6)
/MCU_A2: R20.1, U1.14 (PD5)
/MCU_A3: R21.1, U1.13 (PD4)
/MCU_A4: R22.1, U1.12 (PD3)
/MCU_A5: R23.1, U1.11 (PD2)
/MCU_C0: Q1.1 (G), U1.21 (PC2)
/MCU_C1: Q2.1 (G), U1.22 (PC3)
/MCU_C2: Q3.1 (G), U1.23 (PC4)
/MCU_C3: Q4.1 (G), U1.24 (PC5)
/MCU_C4: Q5.1 (G), U1.25 (PC6)
/MCU_C5: Q6.1 (G), U1.26 (PC7)
/MCU_C6: Q7.1 (G), U1.31 (PA6)
/MCU_C7: Q8.1 (G), U1.32 (PA5)
/MCU_C8: Q9.1 (G), U1.33 (PA4)
/MCU_C9: Q10.1 (G), U1.34 (PA3)
/MCU_C10: Q11.1 (G), U1.35 (PA2)
/MCU_C11: Q12.1 (G), U1.36 (PA1)
/MCU_C12: Q13.1 (G), U1.37 (PA0)
/MCU_C13: Q14.1 (G), U1.40 (PB0)
/MCU_C14: Q15.1 (G), U1.41 (PB1)
/MCU_C15: Q16.1 (G), U1.42 (PB2)
/MCU_C16: Q17.1 (G), U1.44 (PB4)
/MCU_DOT0: R24.1, U1.10 (PD1)
/MCU_DOT1: R25.1, U1.9 (PD0)
/RTC_BATTERY: BT1.1 (+), U2.14 (VBAT), U3.3 (VBAT)
/RTC_SCL: R29.2, U1.19 (PC0), U2.16 (SCL), U3.6 (SCL)
/RTC_SDA: R28.2, U1.20 (PC1), U2.15 (SDA), U3.5 (SDA)
GND: BT1.2 (-), C1.2, C2.2, C3.2, C4.2, C5.2, C6.2, C7.2, C8.2, C9.2, C10.2, C11.2, H1.1, H2.1, H3.1, H4.1, H5.1, J5.4 (GND), J5.5 (Shield), J6.4, J6.6, J6.8, J6.10, Q1.2 (S), Q2.2 (S), Q3.2 (S), Q4.2 (S), Q5.2 (S), Q6.2 (S), Q7.2 (S), Q8.2 (S), Q9.2 (S), Q10.2 (S), Q11.2 (S), Q12.2 (S), Q13.2 (S), Q14.2 (S), Q15.2 (S), Q16.2 (S), Q17.2 (S), Q18.2 (S), R26.2, R31.2, SW1.2, SW2.2, SW3.2, U1.6 (GND), U1.18 (GND), U1.28 (GND), U1.39 (GND), U2.5 (GND), U2.6 (GND), U2.7 (GND), U2.8 (GND), U2.9 (GND), U2.10 (GND), U2.11 (GND), U2.12 (GND), U2.13 (GND), U3.4 (GND), Y2.3
unnamed: BZ1.2 (-), D1.2 (A), Q18.3 (D)
unnamed: C4.1, U1.29 (AREF)
unnamed: C2.1, U1.8 (XTAL1), Y1.1
unnamed: C3.1, U1.7 (XTAL2), Y1.2
unnamed: U3.1 (X1), Y2.1
unnamed: U3.2 (X2), Y2.2

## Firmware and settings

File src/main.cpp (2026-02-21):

#include "alarm/alarm.h"
#include "brightness/brightness.h"
#include "buzzer/buzzer.h"
#include "driver/adc/adc.h"
#include "driver/button/button.h"
#include "driver/calib/persistent_calib.h"
#include "driver/display/display.h"
#include "driver/i2c/i2c.h"
#include "driver/init/init.h"
#include "driver/panic/panic.h"
#include "driver/rtc/buffered_rtc.h"
#include "driver/rtc/ds3231.h"
#include "driver/rtc/irtc.h"
#include "driver/time/time.h"
#include "driver/tone/tone.h"
#include "filter/exponential_filter.h"
#include "page/page_manager.h"
#include "sched/sched.h"

int main(void) {
  Init init{};
  Display display{};
  Panic panic{display};
  Time time{};
  Sched sched{time, panic};
  Tone tone{};
  Buzzer buzzer{sched, tone};
  I2C i2c{I2C::FreqMode::FREQ_400K};
  Ds3231 Ds3231{i2c};
  BufferedRtc rtc{sched, Ds3231};
  PersistentCalib calib{sched, Ds3231};
  Adc adc{Adc::ReferenceMode::AVCC, Adc::PrescalerMode::DIV128};
  constexpr uint8_t brightnessAdcChannel = 7;
  ExponentialFilter filter{5.0f, Brightness::c_updateDelay / 1000.0f};
  Brightness brightness{sched, display, filter, adc, brightnessAdcChannel};
  Button button{sched};
  Alarm alarm{sched, rtc};
  PageEnv pageEnv{sched, time, display, buzzer, button, rtc, Ds3231, calib, alarm};
  constexpr PageType startPageType = PageType::CLOCK_MAIN_PAGE;
  PageManager pageManager{pageEnv, startPageType};

  const auto alarmCb = [](void *ctx) {
    static_cast<PageManager *>(ctx)->changePage(PageType::ALARM_ALERT_PAGE);
  };
  alarm.setCallback(alarmCb, &pageManager);

  for (;;) {
    sched.run();
  }
}

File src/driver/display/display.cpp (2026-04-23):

#include <avr/interrupt.h>
#include <avr/io.h>
#include <string.h>
#include <util/atomic.h>
#include <util/delay.h>

#include "driver/display/display.h"
#include "driver/display/font/font.h"
#include "driver/mem/prog.h"

/******************************************************************************
  Ugly stuff ahead! The idea is to drive dot matrix in software by switching
  displayed column on timer overflow interrupt.

  Global brightness is set up by disabling display on compare interrupt
  of the same timer. If two interrupts become too close, the compare interrupt
  is disabled and the corresponding logic is performed on overflow.

  Per-pixel brightness is set up by treating each display refresh as pixel
  brightness step and enabling or disabling pixels by comparing their values
  to step number.
******************************************************************************/

static constexpr uint8_t c_compareLowest = 25;
static constexpr uint8_t c_compareHighest = 230;

static volatile uint8_t g_column = 0;
static volatile uint8_t g_pixelBrightnessStep = 0;
static volatile uint8_t g_buf[2][Display::c_height * Display::c_width];
static volatile uint8_t *g_fgBuf = g_buf[0];
static volatile uint8_t *g_bgBuf = g_buf[1];

struct ColumnPin {
  volatile uint8_t *port;
  uint8_t mask;
  uint8_t maskInv;
};

static const ColumnPin c_columnPins[] = {
    {&PORTC, (uint8_t)(1 << 2), (uint8_t)~(1 << 2)}, // C0
    {&PORTC, (uint8_t)(1 << 3), (uint8_t)~(1 << 3)}, // C1
    {&PORTC, (uint8_t)(1 << 4), (uint8_t)~(1 << 4)}, // C2
    {&PORTC, (uint8_t)(1 << 5), (uint8_t)~(1 << 5)}, // C3
    {&PORTC, (uint8_t)(1 << 6), (uint8_t)~(1 << 6)}, // C4
    {&PORTC, (uint8_t)(1 << 7), (uint8_t)~(1 << 7)}, // C5
    {&PORTA, (uint8_t)(1 << 6), (uint8_t)~(1 << 6)}, // C6
    {&PORTA, (uint8_t)(1 << 5), (uint8_t)~(1 << 5)}, // C7
    {&PORTA, (uint8_t)(1 << 4), (uint8_t)~(1 << 4)}, // C8
    {&PORTA, (uint8_t)(1 << 3), (uint8_t)~(1 << 3)}, // C9
    {&PORTA, (uint8_t)(1 << 2), (uint8_t)~(1 << 2)}, // C10
    {&PORTA, (uint8_t)(1 << 1), (uint8_t)~(1 << 1)}, // C11
    {&PORTA, (uint8_t)(1 << 0), (uint8_t)~(1 << 0)}, // C12
    {&PORTB, (uint8_t)(1 << 0), (uint8_t)~(1 << 0)}, // C13
    {&PORTB, (uint8_t)(1 << 1), (uint8_t)~(1 << 1)}, // C14
    {&PORTB, (uint8_t)(1 << 2), (uint8_t)~(1 << 2)}, // C15
    {&PORTB, (uint8_t)(1 << 4), (uint8_t)~(1 << 4)}, // C16
};
static constexpr uint8_t c_pinMaskA = 0b01111111;
static constexpr uint8_t c_pinMaskB = 0b00010111;
static constexpr uint8_t c_pinMaskC = 0b11111100;
static constexpr uint8_t c_pinMaskD = 0b11111111;

static inline void displayInit() {
  // Init outputs
  DDRA |= c_pinMaskA;
  DDRB |= c_pinMaskB;
  DDRC |= c_pinMaskC;
  DDRD |= c_pinMaskD;

  // Timer 2, fast PWM mode, F_CPU/8
  TCCR2 = (1 << WGM21) | (1 << WGM20) | (0 << CS22) | (1 << CS21) | (0 << CS20);
  // Set output compare (medium brightness)
  OCR2 = 127;
  // Enable the compare interrupt and overflow interrupt
  TIMSK |= (1 << OCIE2) | (1 << TOIE2);
}

static inline void displayDeinit() {
  // De-init outputs
  PORTA &= ~c_pinMaskA;
  PORTB &= ~c_pinMaskB;
  PORTC &= ~c_pinMaskC;
  PORTD &= ~c_pinMaskD;
  DDRA &= ~c_pinMaskA;
  DDRB &= ~c_pinMaskB;
  DDRC &= ~c_pinMaskC;
  DDRD &= ~c_pinMaskD;

  // De-init timer
  TCCR2 = 0;
  OCR2 = 0;
  TIMSK &= ~((1 << OCIE2) | (1 << TOIE2));
}

static inline void displaySetBrightness(uint8_t brightness) {
  OCR2 = brightness;
  if (OCR2 < c_compareLowest || OCR2 > c_compareHighest) {
    // Compare and overflow interrupts are too close
    // Let's disable compare interrupt and do everything on overflow
    TIMSK &= ~(1 << OCIE2);
  } else {
    // Enable compare interrupt
    TIMSK |= (1 << OCIE2);
  }
}

static inline uint8_t displayGetBrightness() {
  return OCR2;
}

static inline bool displayEnableRows() {
  const uint16_t offset = g_column * Display::c_height;
  uint8_t maskD = (g_fgBuf[offset + 4] > g_pixelBrightnessStep) << 0 | // DOT1
                  (g_fgBuf[offset + 1] > g_pixelBrightnessStep) << 1 | // DOT0
                  (g_fgBuf[offset + 5] > g_pixelBrightnessStep) << 2 | // A5
                  (g_fgBuf[offset + 4] > g_pixelBrightnessStep) << 3 | // A4
                  (g_fgBuf[offset + 3] > g_pixelBrightnessStep) << 4 | // A3
                  (g_fgBuf[offset + 2] > g_pixelBrightnessStep) << 5 | // A2
                  (g_fgBuf[offset + 1] > g_pixelBrightnessStep) << 6 | // A1
                  (g_fgBuf[offset + 0] > g_pixelBrightnessStep) << 7;  // A0
  PORTD = maskD;
  return maskD;
}

static inline ColumnPin displayGetColumnPin() {
  return c_columnPins[g_column];
}

static inline void displayEnableColumn(const ColumnPin &columnPin) {
  *columnPin.port |= columnPin.mask;
}

static inline void displayDisableColumn(const ColumnPin &columnPin) {
  *columnPin.port &= columnPin.maskInv;
}

static inline void displayNextPixelBrightnessStep() {
  g_pixelBrightnessStep++;
  if (g_pixelBrightnessStep >= Display::c_maxPixelBrightness) {
    g_pixelBrightnessStep = 0;
  }
}

static inline void displayNextColumn() {
  g_column++;
  if (g_column >= Display::c_width) {
    g_column = 0;
    displayNextPixelBrightnessStep();
  }
}

ISR(TIMER2_OVF_vect) {
  if (OCR2 > c_compareHighest) {
    // Highest possible brightness
    // Disable column immediately before enabling the next one
    displayDisableColumn(displayGetColumnPin());
  }

  displayNextColumn();
  ColumnPin columnPin = displayGetColumnPin();
  if (displayEnableRows()) {
    // Enable column only if there is something to display: this counteracts capacitance-related
    // ghosting for empty columns. The same issue for non-empty columns is counteracted by keeping
    // rows active even when column is already disabled.
    displayEnableColumn(columnPin);
  }

  if (OCR2 < c_compareLowest) {
    // Lowest possible brightness
    // Disable column immediately after enabling it
    displayDisableColumn(columnPin);
  }
}

ISR(TIMER2_COMP_vect) {
  displayDisableColumn(displayGetColumnPin());
}

/******************************************************************************
  Slighly less ugly stuff ahead: C++ interface part
******************************************************************************/

Display::Display() {
  displayInit();
}

void Display::setGlobalBrightness(uint8_t brightness) {
  displaySetBrightness(brightness);
}

uint8_t Display::getGlobalBrightness() {
  return displayGetBrightness();
}

void Display::update() {
  ATOMIC_BLOCK(ATOMIC_RESTORESTATE) {
    auto tmp = g_fgBuf;
    g_fgBuf = g_bgBuf;
    g_bgBuf = tmp;
  }
  memcpy((void *)g_bgBuf, (void *)g_fgBuf, c_height * c_width);
}

void Display::clear() {
  memset((void *)g_bgBuf, 0, c_height * c_width);
}

void Display::writePixel(uint8_t x, uint8_t y, uint8_t brightness) {
  if (x < c_width && y < c_height) {
    g_bgBuf[x * c_height + y] = brightness;
  }
}
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

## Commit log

2025-01-07 Reorganize drivers
2025-01-07 Use timer interrupts in display driver
2025-01-07 Add buzzer driver
2025-01-08 Display driver improvemets
    - Increase refresh rate
    - Special workarounds for lowest and highest brigtness
    - Support per-pixel brightness (with low refresh rate)
    - Bitmap write API
    - Transpose display buffer layout to make bitmaps more readable in code
    [display.cpp, display.h, main.cpp]
2025-01-08 Implement I2C driver, actual ticking clock demo
2025-01-09 RTC driver test
2025-01-09 Fix per-pixel brigtness blinking
    [display.cpp]
2025-01-09 Workaround for ghosting on low brigtness
    [display.cpp]
2025-01-12 Button read test
2025-01-12 Clock page test
    Also, various type and bug fixes
    [brightness.cpp, display.cpp, display.h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]
2025-01-12 Temperature read test
2025-01-12 Fix non-uniform column intensity for lowest brightness
    [display.cpp]
2025-01-14 String support in display driver
2025-01-14 Dynamic page switching test
2025-01-16 Buffered RTC driver
2025-01-16 Support negative temperatures
2025-01-17 Implement missing destructors
    Also enable interrupts through a separate module
    [adc.cpp, brightness.cpp]
2025-01-17 Eeprom abstraction + move alarm module out of drivers
2025-01-17 Button driver cleanup
2025-01-18 Make button driver more noise-tolerant by ignoring short pulses
2025-01-18 Add harware design files to repo
    [ControllerFrame.dwg, ControllerFrame.dxf, MatrixFrameLong.dwg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]
2025-01-18 Make LED holes smaller
    The 0.9 hole size turned out to be too wiggly, 0.8 should work better
    [superclockmatrix.gbl, superclockmatrix.gbo, superclockmatrix.gbp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]
2025-01-19 Mention buzzer resistance on schematic
    [SuperClockController.kicad_sch]
2025-01-20 Controller PCB revision 3.1
    - Add cathode pull-ups. It seems to be the only proper way to deal with ghosting and flickering on lowest brightness
    - Connect all anodes to one MCU port, should provide more opportunities to software.
    - Use smaller silk-screen outline for CR2032 holder (the previous one was visibly offset for my battery holder).
    - Update component numbering with a more sensible scheme: cathode FETs and resistors are now numbers 1-17.
    - Use bigger footprint and bigger value for power input capacitor.
    - Add missing capacitor to one of MCU power pins.
    - Move crystal closer to MCU.
    [SuperClockController.kicad_sch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]
2025-01-22 Add schematics in PDF
2025-03-10 Reorder stuff on schematic for better readability + update to KiCAD 9.0
    [SuperClockController.kicad_sch]
2025-03-10 Replace IRLML2505 to AO3416A
    This one claims to have ESD-protected gates, should be easier to handle
    [SuperClockController.kicad_sch]
2025-03-15 Update display driver to match controller rev. 3.1 pinout
2025-03-15 Use exponential filter for brightness regulation
2025-03-15 Define alpha through frequency and delta in exponential filter
    To my delight, GCC optimizes out these calculations, so binary size does not change, but the meaning of alpha coefficient becomes much more clear.
2026-02-21 Add panic driver and use it in scheduler
    A failed `addTask` is something that generally can't be recovered from, so let's halt with an error code instead of returning a value that is never checked.
    [main.cpp]
2026-02-21 DS3231 calibration support
    It is now possible to set the DS3231 "aging" register value during clock setup
2026-04-23 Fix alarm saving bug and a few other minor issues
    [display.cpp, i2c.cpp]
2026-05-20 Mark R1-R17 as DNP, replace AO3416 with 2N7002K and update docs.
    It turned out that green LEDs do not like the reverse voltage at all, and they started slowly failing in a few months. So let's combat LED ghosting by using MOSFETs with lower parasitic capacitance instead of adding pull-up resistors.
    [SuperClockController.kicad_pcb, SuperClockController.kicad_sch]
